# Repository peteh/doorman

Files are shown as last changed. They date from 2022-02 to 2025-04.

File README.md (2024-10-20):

# Doorman

Doorman is an ESP32 or ESP8266 based mqtt bridge to connect your [TCS](https://www.tcsag.de/) or [Koch](https://www.kochag.ch/) Intercom to any home automation system.

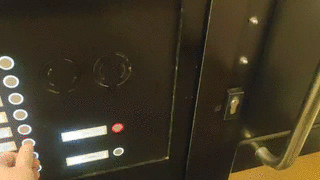
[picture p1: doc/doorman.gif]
doorman opener


## Main Features

* Support for TCS bus based intercom systems from TCS AG (Germany) or Koch AG (Switzerland)
* Automatic Homeassistant discovery via MQTT
* MQTT integration for all messages read from the bus and for writing messages to the bus
* Button push pattern detection - you can define a pattern and assign a code that is written to the bus if the pattern is detected (Example: automatically open the door if the doorbell is pressed x times in a certain way). A successfully detected pattern is also published via mqtt.
* Party mode (When this is enabled, the door opener automatically opens if the door bell is pressed)

### Party Mode

When Party mode is enabled, a code (default: entry door buzzer code) is automatically sent when a certain code has been received on the bus (default: entry door bell code).

This allows you to enable party mode during a party and your guests can just enter by pressing your door bell when they arrive or go for a smoke.

Party mode can be turned on or off by using the switch on in Homeassistant, or by quickly lifting up you handset 3x (if your handset code has been configured correctly).

## How to get Codes

Connect doorman to an mqtt broker by setting up WiFi credentials and mqtt broker.

If you already have Homeassistant configured with the mqtt integration on the same broker, go to Settings -> Devices -> Doorman. You should see a text entity called "TCS Bus". This entity allows to read all messages from the bus and write to the bus. Do the action for the signal you want to get the code of (apartment door bell, entry door bell or lifting up your handset). In the history of the TCS Bus entity you should see all codes that have been read from the bus. Then you can copy the values to the configuration settings in the home assistant device.

The codes that are specific to your flat are the long ones (without 0000 prefix).

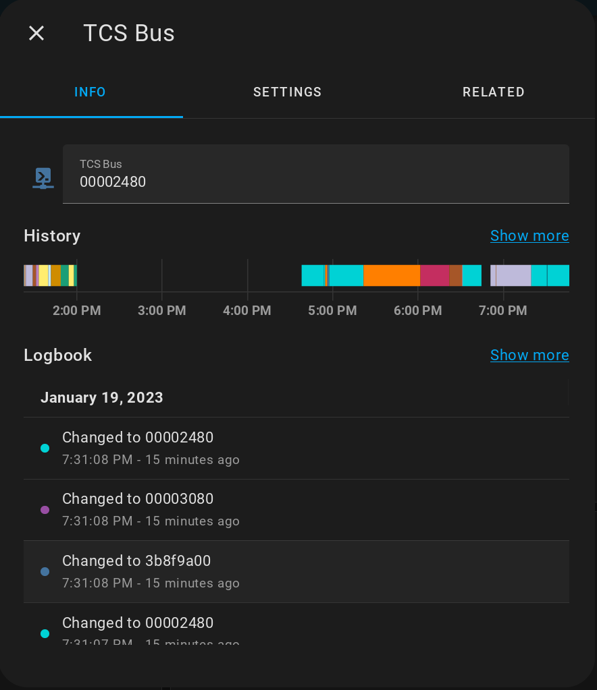
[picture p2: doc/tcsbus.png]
TCS Bus


## Prebuilt PCB and Case

AzonInc created a PCB with the doorman circuits and 3D printable housing. The project supports integration via ESPhome.

You can find more information [here](https://doorman.azon.ai) or in the [repository](<https://github.com/AzonInc/Doorman>).

## Wiring

wiring
If you open your phone in your flat (check TCS website for manuals), you will probably find the following screw terminal lines: A, B, E, P. 

A and B are the bus lines. You have to make sure which one is 24V+ and wire this to A of the setup. The other one is GND. 

The P line can be used for power supply. You can also skip the part and power through the USB port of the Wemos D1. 

### Part list

* 1x Microcontroller 1x (Choose one)
  * Wemos D1 Mini (based on ESP8266, does have single color led) [Buy on Amazon (partner link)](https://amzn.to/3VmqxsN) / [Buy on aliexpress (partner link)](https://s.click.aliexpress.com/e/_Dkct0Yl)
  * Wemos S2 Mini (based on ESP32-S2, does not have led) [Buy on Amazon (partner link)](https://amzn.to/3nkMbRq) / [Buy on aliexpress (partner link)](https://s.click.aliexpress.com/e/_Dnoy8df)
  * Wemos S3 Mini (based on ESP32-S3, does have RGB led)
* 1x ULN2003A (to send commands to the bus) [Buy on Amazon (partner link)](https://amzn.to/48Qoq6i)
* 1x Traco TSR1 2405 (dc/dc 24V to 5V as power supply for the controller to power it from the door bell system) [Buy on Amazon (partner link)](https://amzn.to/49iwwUZ)
* 1x tripple screw terminal (to connect to the bus) [Buy on Amazon (partner link)](https://amzn.to/3OrmcSC)
* 2x double screw terminal (optional, to connect switch and led) [Buy on Amazon (partner link)](https://amzn.to/3OrmcSC)
* 1x 1 MOhm resistor
* 1x 1 kOhm resistor
* 1x 147 kOhm
* 1x 10k Ohm resistor (only needed to wire a button)
* 1x 330 Ohm resistor (only needed to wire a led)
* 2x 1.2 Ohm resistors

## TODO

There are still a view things open.

* Allow wifi/mqtt configuration without the need for project compilation

## Credits

Doorman is heavily built on the code and the information of the following two projects:

**Doorman S3** PCB and case for TCS intercom with ESPhome firmware \
<https://github.com/AzonInc/Doorman>

**TCSIntercomArduino** different methods to read from and write to TCS bus \
Reverse Engineering video: <https://www.youtube.com/watch?v=xFLoauqj9yA&t=11s> \
<https://github.com/atc1441/TCSintercomArduino>

**tcs-monitor** an mqtt monitor for listening to the TCS bus \
Blog Post: <https://blog.syralist.de/posts/smarthome/klingel/> \
<https://github.com/Syralist/tcs-monitor>

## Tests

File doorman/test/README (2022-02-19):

This test set can be used with platformio's unity.h environment.

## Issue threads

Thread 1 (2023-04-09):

TCS-Reader Question

manuelkamp, 2023-04-09:
Hi, can you please explain to me how exactly the TCS Reader works? Unfortunately I am not very familiar with the used language in this project as is. As I am working on a similar project (but on raspberry pico with micropython), and my approach is not really working (I get a different message every time I ring my bell), I appreciate any help and/or explanation. What really confuses me is the fact, that one message I have recorded seems to be the correct one, If I am writing this message to the bus, my bell rings. But as I said, my reader reads a different message every time (and therefore it is not reliable). thank you very much!

peteh, 2023-04-10:
Hi,

you can start with the youtube video from the credits from me readme. I took the code from these projects for reading the data.

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

My guess is that your code is not accurate enough for the timing as it's pretty important to interpret the numbers right. That's why the interrupt based routine that I use in my code is most reliable from what I've tried so far.

peteh, 2023-04-12:
I'll close here and reopen if there are further questions

Closed 2023-04-12.

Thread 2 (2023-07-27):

Writing to bus not working.

BuergerJulian, 2023-07-27:
Hello,
i'm in the process of using the project.
Reading the bus is no problem, but writing doesn't work in my case.
When I send the code to open the door, nothing happens.

am i the only one with the problem?

Best Regards
Julian

peteh, 2023-07-27:
Not sure if many people use it. I'm using two of the devices. I've one 8266 d1 wemos and one s3 mini currently working with both reading and writing. Did you double check the wiring?

BuergerJulian, 2023-07-28:
Yes is rechecked the wiring, it looks okay.

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

peteh, 2023-07-28:
Can you take a high def picture of your wiring setup and a separate one where you connected to the bus? Otherwise it's kinda impossible to see what is wrong.

If you send codes manually it probably shows up there too but during writing reading is disabled. Thus it is not read from the bus but published based on what were were writing.

BuergerJulian, 2023-07-28:
Please don't laugh at soldering skills, I don't do that very often.

I hope you can see something.

Green = A (24V BUS)
White = B (GND)
Orange = P (24V)

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

peteh, 2023-07-28:
Normally the power line of the door bell should be sufficient. Only the bus 24v goes to 0 when sending a message. But if you can use a USB power supply it's also fine.

Glad you figured it out. You're officially the third person that I know of that uses this project after me and my neighbor :D

BuergerJulian, 2023-07-28:
It's a great project!
I would have thought more people would use it.

How can it be that there is no longer any voltage on the P line when I execute the command?

When I press the original door opener it doesn't happen.

It would be really nice if it would work without an extra power supply. So I have to lay an extra cable across the hallway.

peteh, 2023-07-28:
Good question,

normally it should not happen and means that the system detected a fault and is power cycling. It can happen if you send 0000 for example or commands the system cannot handle. So if you disconnect P line from the device and you still measure a drop to 0 on the P-line that does not happen when you press the door opener button, something is still wrong and it's not a power supply issue.

Only the A or B line from the bus should be pulled to 0 when sending commands. My powerline is stable for several weeks. You can see in the devices view in homeassistant under diagnostics of the doorman device the restart counter. If it power cycles it will increase that counter if you get your power from the P line.

Is your command actually executed - as in, does the doorbell ring if you send the ring code or does the buzzer open the door?

Can you double check the resistors on the board and their values?

There is a great video from Aaron where he explains how the system works: https://www.youtube.com/watch?v=xFLoauqj9yA

I built doorman based on the two projects linked in the credits of the readme as I'm not an electrician but rather a software guy. Maybe the video can give you some ideas what to check.

BuergerJulian, 2023-07-28:
I'm using a 150k resistor instead of the 147k, do you think that will make a big difference?

peteh, 2023-07-29:
The 147k Ohm resistor is for the voltage divider to scale down the 24V to 3.3V for the inputs. It does not impact the writing part of the device. You have to double check everything around the ULN2003 that is related to writing.

I also have no idea yet what else to check. Are you by accident sending 0000? Are you using the buttons to send the commands or the tcs bus text field in homeassistant, or directly via mqtt?

BuergerJulian, 2023-07-30:
> edit: I had another idea, do you maybe have a short from P line and 24V+ bus line? Does the issue happen that P goes to 0 if you don't connect it to the board? To test: only connect A and B to the door bell and leave P disconnected and power the board via USB. If P does not go down in this case your wiring of the P-line on the board is somewhere faulty.

Yes, that's the problem.
Now i just need a solution for this.

peteh, 2023-07-30:
You can try to find the short on the board by tracing the lines with a multimeter after you removed potential shorts.

By the way, I'd recommend to install the esp32 using female headers to add or remove the controller easier when you mess up the board:

https://gct.co/connector/bd080

As the other components are fairly cheap, you can have several iterations of the board. I'm using 1 strand wires with isolation rather than big solder blobs to make the connections. Still a pain in the ass to solder but a bit cleaner.
Mine for example looks like this:

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

BuergerJulian, 2023-07-30:
I soldered everything again, but I still have the same problem.
Brown = P 24V
White = B GND
Green = A 24V

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

peteh, 2023-07-30:
Looks ok from the front side. Can you also show the back side again?

Just for my understanding, does the controller turn off/restart when it's not powered by USB but only connected to P line when you send a message?

How are you measuring that the P line goes to 0? By measuring GND and P directly at the screw terminals of the intercom? How long does it stay at 0?

BuergerJulian, 2023-07-30:
> Looks ok from the front side. Can you also show the back side again?
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
>
> Just for my understanding, does the controller turn off/restart when it's not powered by USB but only connected to P line when you send a message?
Yes, exactly.
>
> How are you measuring that the P line goes to 0? By measuring GND and P directly at the screw terminals of the intercom? How long does it stay at 0?
Yes, I measure between GND and P on the terminal.
The voltage stays at 0v for about 1-2 seconds.

peteh, 2023-07-30:
Let's try to narrow it down a bit:
Sending wrong commands: we can exclude that because P line stays up when powered through USB

Wiring: I couldn't find obvious issues in your wiring yet, I can't double check the resistor values but I assume that you measured them before you soldered. So maybe nothing wrong there either.

Power consumption. If I remember correctly the data sheet says we have about 100 to 200mA at 24V for a connected device on the bus which should be plenty. The traco can provide up to 1A at 5V. I don't know what happens when you draw more. 1A should be plenty for the setup though. The only difference here is that you're using another dev board than me. I think yours has a few more parts on it than a d1 mini/s2 mini/s3 mini - those I've tested working in my setup and with stable power supply. I doubt you have one of those lying around to exclude the dev board though.

Other ideas I currently don't have yet

BuergerJulian, 2023-07-30:
I have now ordered a d1 mini,
I'll try it with that tomorrow.

Thanks for your help!

BuergerJulian, 2023-07-31:
Also not working with the d1 mini :(

peteh, 2023-07-31:
Then I'm also a bit at the end. Can you take a picture of the intercom itself and the wiring maybe?
Worst case you have to go with the usb power method for now.

BuergerJulian, 2023-08-02:
> A few more ideas from more likely to less likely being an issue after reading about similar issues in other projects:
>
> * Many people suggest to add capacitors when brownouts happen (high current peaks that we probably generate when we want to send messages followed by the power supply not being able to provide them quickly). It would charge and then the esp could use the charge from the capacitor rather than pulling from the psu. However, I've never needed them so far, so I have no idea how to wire them properly into the circuit. But maybe a good next approach to try.

> * What's the actual voltage on the bus and the P line? Is it actually 24V?

B -> P = 22V
B -> A = 24V

> * Are P line and one of the bus lines potentially shorted on the board or on the actual intercom?

I do not think so.

> * How long are the cables actually? I don't think voltage drops are a big issue, but if you use very long cables it might.

My cables are only 10cm long.

The microcontroller only draws 23mA, even if I send a command, I just measured that.

peteh, 2023-08-02:
Mhm, then I have no further ideas. I'd personally still try the capacitor solution, but other than that I'd probably go for a separate power supply then.

peteh, 2024-01-24:
@BuergerJulian If you are still interested in getting yours to work, check out  #4

He solved it using a cap to stabilize power supply.

BuergerJulian, 2024-01-25:
> @BuergerJulian If you are still interested in getting yours to work, check out #4
>
> He solved it using a cap to stabilize power supply.

I will give it a try, thank you!

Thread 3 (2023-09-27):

Installation/Compiling instructions/documentation

mStirner, 2023-09-27:
Hey,

first, thanks for the project/work.

I wanted to start using it, but have no clue how to compile/build the project and how to flash it.
Would it be possible to write a short guide/documentation on how to build and flash it?

Thanks in advance.

peteh, 2023-09-27:
Hi Marc,

I think adding detailed instructions is a bit redundant as it's the standard way to open a project in vscode with platform io and flash it to a standard dev board.

You will need vscode with platformio extension installed on your pc.

You will have to rename config.h.sample to config.h in the project and enter your wifi/mqtt details.

You can more or less follow this instruction about how to build a project with platform io: https://www.youtube.com/watch?v=nlE2203Q3XI

Let me know if you get stuck somewhere after watching the video.

mStirner, 2023-12-03:
Sorry for the late response.

I cant use PlatformIO, it throws a error when i try to open "PIO Home" in VSCode. (https://github.com/platformio/platformio-vscode-ide/issues/3912)
Is there a way to build & upload the project from a other way, especially the sample codes?

peteh, 2023-12-03:
You can always build in Arduino IDE.

1. Rename the main.cpp to main.ino
2. You might have to remove the Arduino.h import in main.ino
3. You have to manually install all the libraries that are listed in platformio.ini

Platformio is pretty stable if you don't run on 4 year old LTS versions of your operating system (based on your kernel I assume you are running ubuntu 20.04). My guess is that there is a python incompatibility because you are still on Python 3.6 while the most recent version is python 3.12 and most distros run on 3.10 or 3.11.

Your problem is this:
https://stackoverflow.com/questions/52796630/python3-6-attributeerror-module-asyncio-has-no-attribute-run

The functionality used that produces your error in platformio is because the functionality has only been added in Python 3.7 but you are running python 3.6.

If you want to use it on your old system, you could look into pyenv, but it's also a painful path.

My recommendation is to update to the latest LTS version which is 22.04. This would solve your issue as it ships with python 3.10.

dbro, 2025-05-12:
In case it's helpful for future reference, I can provide some comments here to guide people who want a walkthrough to install the platform IO command line version (does not involve VSCode).

clone the repository:
git clone https://github.com/peteh/doorman

install platform io by following the [installation instructions here] (https://docs.platformio.org/en/latest/core/installation/methods/installer-script.html) and also installing the [shell commands](https://docs.platformio.org/en/latest/core/installation/shell-commands.html) and the [udev rules](https://docs.platformio.org/en/latest/core/installation/udev-rules.html)

create a doorman/src/config.h file using the example from the repo, and edit the doorman/platformio.ini file if necessary (I needed to use /dev/ttyUSB0)

connect the device via USB, build and upload the firmware with this command: pio run -e d1-mini -t upload

visit the url assigned to the device by your DHCP server and continue setting up there

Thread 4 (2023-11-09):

No Codes :(

alkue1, 2023-11-09:
Hello,
I am enthusiastic about your project and have soldered together a board according to the instructions. Flashing the d1mini also worked without any problems. The connection to Homeassistant also works. Unfortunately, I do not get any values displayed in the TCS bus. Is it possible to narrow down the source of the error?
I have attached a picture of the circuit board and the wall unit.

I tried it with USB power supply, and also flashed different d1 minis. for the 147kohm I connected 100 and 47 in series.

Regards
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

peteh, 2023-11-19:
Mhm, hard to tell. Looks good from here at least.
Are you measuring something on the D5 pin? (measure with multimeter to GND). There we should measure something around 3V.
If you don't you could connect the P line instead of 24V+ from the bus to have a stable 24V and check again.

alkue1, 2023-11-20:
I have since found out that there was an occasional short circuit with very low currents on the board. I was able to solve the problem with a new board.  Now I can send and receive messages with power via USB

Now, unfortunately, I have the same problem as in the closed issue, that the power supply from the Traco breaks down during the transmission process.

I was also able to solve this problem with an external stepdown converter with two capacitors (like "DollaTek DC-DC 24V/12V to 5V"). Now I can send, but not receive

There is now approx. 3.05V on D5 and the voltage drops when a message arrives on the bus. Is 3.05 sufficient for reception?

I have also noticed a lot of noise in the loudspeaker when operating via P. Is there a way to avoid this?

Many thanks for the help and the great project

peteh, 2023-11-20:
> There is now approx. 3.05V on D5 and the voltage drops when a message arrives on the bus. Is 3.05 sufficient for reception?
>
That sounds alright, so the led on the wemos d1 is also not blinking, e.g. when you lift up the handset?
I just reflashed the latest master code to see if it's working in general and my led blinks when there is something on the bus, so the code should be fine.

If you want to run further tests, just write a small program that sends something over serial when the output of digitalRead(D5) changes. Then you can see if the D5 input works in general when you lift up the handle or press the door opener button on the tcs device.

> I have also noticed a lot of noise in the loudspeaker when operating via P. Is there a way to avoid this?
>
For me, I haven't noticed, but I'm also running on the traco. I'm unfortunately no electric expert, my guess is that the power supply of your TCS system is not handling this well (there are only some 100mW to be drawn from the P line per device).
> Many thanks for the help and the great project

alkue1, 2023-11-22:
> blinking, e.g. when you lift up the handset?

The software seems to work perfectly. The lamp now flashes briefly when sending and receiving.

> my guess is that the power supply of your TCS system is not handling this well (there are only some 100mW to be drawn from the P line per device).

i think you are absolutely right. It seems as if the power supply breaks down for som milliseconds and forces the d1 mini to restart. I have now added a relatively large capacitor in front of the traco. At the moment everything seems to be working as it should.  :)

The last step will be a PCB so that everything fits into the existing cover in the end.

Many thanks for the support - solved!

peteh, 2023-11-22:
If you're making a pcb I'm very interested in having one or two as well and I'd also add the pcb files to the repo if you share them.

I'm also interested in your capacitor solution which could maybe solve the problem of the person from the other issue. Then I could include it in general in the drawings.

Closed 2023-11-22.

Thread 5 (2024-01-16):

"esp_task_wdt.h" missing when building project

NonProgrammerCharacter, 2024-01-16:
**Description:**
When building the project for a d1-mini in VsCode with Platformio on Windows I get the following error message.
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

I have tried finding where that file comes from but I can only find it online as part of this github "https://github.com/pycom/esp-idf-2.0/blob/master/components/esp32/include/esp_task_wdt.h".
Is it part of some ESP32 libraries which cant be used on a ESP8266 board?

**Trace:**
```
Processing d1_mini (platform: espressif8266; board: d1_mini; framework: arduino)
--------------------------------------------------------------------------------------------------------------------------------------------------------------------------------------------------------------------------------------------Verbose mode can be enabled via `-v, --verbose` option
CONFIGURATION: https://docs.platformio.org/page/boards/espressif8266/d1_mini.html
PLATFORM: Espressif 8266 (4.2.1) > WeMos D1 R2 and mini
HARDWARE: ESP8266 80MHz, 80KB RAM, 4MB Flash
PACKAGES:
 - framework-arduinoespressif8266 @ 3.30102.0 (3.1.2)
 - tool-esptool @ 1.413.0 (4.13)
 - tool-esptoolpy @ 1.30000.201119 (3.0.0)
 - toolchain-xtensa @ 2.100300.220621 (10.3.0)
LDF: Library Dependency Finder -> https://bit.ly/configure-pio-ldf
LDF Modes: Finder ~ chain, Compatibility ~ soft
Found 44 compatible libraries
Scanning dependencies...
Dependency Graph
|-- ArduinoJson @ 6.21.5
|-- PubSubClient @ 2.8.0
|-- libesplog @ 0.0.1+sha.335d30f
|-- libmqttdisco @ 0.0.1+sha.af15d5c
|-- ArduinoOTA @ 1.0
|-- DNSServer @ 1.1.1
|-- ESP8266mDNS @ 1.2
|-- ESP8266WebServer @ 1.0
|-- ESP8266WiFi @ 1.0
|-- LittleFS @ 0.1.0
|-- tcsbus
|-- pattern
Building in release mode
Compiling .pio\build\d1_mini\src\main.cpp.o
Archiving .pio\build\d1_mini\lib328\libPubSubClient.a
Archiving .pio\build\d1_mini\lib316\libesplog.a
Archiving .pio\build\d1_mini\lib1d7\libmqttdisco.a
Compiling .pio\build\d1_mini\liba26\ESP8266WiFi\WiFiClientSecureBearSSL.cpp.o
Compiling .pio\build\d1_mini\liba26\ESP8266WiFi\WiFiServer.cpp.o
Compiling .pio\build\d1_mini\liba26\ESP8266WiFi\WiFiServerSecureBearSSL.cpp.o
Compiling .pio\build\d1_mini\liba26\ESP8266WiFi\WiFiUdp.cpp.o
Compiling .pio\build\d1_mini\liba26\ESP8266WiFi\enable_wifi_at_boot_time.cpp.o
Compiling .pio\build\d1_mini\lib938\ESP8266mDNS\ESP8266mDNS.cpp.o
Compiling .pio\build\d1_mini\lib938\ESP8266mDNS\LEAmDNS.cpp.o
Compiling .pio\build\d1_mini\lib938\ESP8266mDNS\LEAmDNS_Control.cpp.o
Compiling .pio\build\d1_mini\lib938\ESP8266mDNS\LEAmDNS_Helpers.cpp.o
Compiling .pio\build\d1_mini\lib938\ESP8266mDNS\LEAmDNS_Structs.cpp.o
Compiling .pio\build\d1_mini\lib938\ESP8266mDNS\LEAmDNS_Transfer.cpp.o
Compiling .pio\build\d1_mini\lib85e\ArduinoOTA\ArduinoOTA.cpp.o
Compiling .pio\build\d1_mini\lib720\DNSServer\DNSServer.cpp.o
Compiling .pio\build\d1_mini\lib3ba\ESP8266WebServer\detail\mimetable.cpp.o
Compiling .pio\build\d1_mini\lib68b\LittleFS\LittleFS.cpp.o
Archiving .pio\build\d1_mini\lib3ba\libESP8266WebServer.a
src\main.cpp:27:10: fatal error: esp_task_wdt.h: No such file or directory

**********************************************************************
* Looking for esp_task_wdt.h dependency? Check our library registry!
*
* CLI  > platformio lib search "header:esp_task_wdt.h"
* Web  > https://registry.platformio.org/search?q=header:esp_task_wdt.h
*
**********************************************************************

   27 | #include <esp_task_wdt.h>
      |          ^~~~~~~~~~~~~~~~
compilation terminated.
*** [.pio\build\d1_mini\src\main.cpp.o] Error 1
======================================================================================================== [FAILED] Took 3.43 seconds ========================================================================================================
```

NonProgrammerCharacter, 2024-01-16:
Now it went through flawlessly.

I assumed it wasn´t meant to be used on the ESP8266, at least the watch-dog stuff but wasn´t sure.

Thank you for the patch.

Closed 2024-01-16.

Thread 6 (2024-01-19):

Integration for the E terminal line

NonProgrammerCharacter, 2024-01-19:
**Help Wanted** (as I can not add labels)

Is it possible to integrate the E line into the microcontroller, which is used for the bell button in front of the apartment door, so I can work with it in Homeassistant?

I would only want it to be the same like the the bell button on the front door, but I guess this one does not run over the bus, so it would only need to register if there is a signal or not which I then would use to create a signal in Homeassistant I can automate with.

This is my first little project and pretty much my first time wiring, soldering and programming stuff like this so it´s a little to much for me.
Im only asking for help with the wiring, the programming I would probably manage by myself somehow.

NonProgrammerCharacter, 2024-01-20:
I dont understand what you mean with wire a relay, wouldnt I just have to look what voltage runs through the contact when the button is pressen and use an appropriate resistor to reduce it to a ESP usable level and wire it to an input (as far as I understood this)?
I only want to see on the ESP if the button is pressed as I would then programm Homeassistant to send a signal to my phone and maybe open the apartment door (with a Nuki Smart Lock or something).

I mean the third bell wire, A, B, E and P, E is used for the bell button directly infront of the apartment door.

This one is not the correct modell but the same contacts, my configuration is with only 3 wires (rightmost graphic) with only A, B, E. (it´s in german, should be a problem as the text is irrelevant for this)
https://www.tcsag.de/fileadmin/user_upload/TCS_DE/Metanavigation/Downloads/ARCHIV/Innenstationen/PI_TTS2.pdf

peteh, 2024-01-20:
Ah now I think I get it. I thought we are talking to simulate a press on the "Etagenruftaster".

Measure what's the voltage. I guess it's around 24V when it's pressed as it connects to the P line when pressed.

Thus you should be able to use the same voltage divider as used for bus reading.

When you look at the wiring:
https://github.com/peteh/doorman
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
Check the green cable going from Bus 24V through the resistors and into the blue cable.

That's a voltage divider that reduces the 24V down to the ESP-readable range.

Wire the same setup with identical two resistors to another input (maybe measure before to get a 0V and ~ 3.3V signal when pressing the switch).

Then you can either read the state with digitalRead in every main loop cycle or add another interrupt routine for the new input.

You probably have to debounce it as well.

peteh, 2024-01-20:
@NonProgrammerCharacter

I created a branch and PR with the necessary changes: feature/etr

See the PR for details: #7

I cannot test it though. However, if you put a voltage divider on D7 it should work.

PS: are you sure the system puts no code on the bus when the floor button is pressed? If it does I can also create an entity that just reacts on a code which would be less wiring.

NonProgrammerCharacter, 2024-01-22:
Based on your drawing the new voltage divider should connect to 5V on the D1-mini, I guess thats not supposed to be like that so I connected it to GND (I couldnt find a better looking software which had the parts needed, which programm did you use for your graphic?).
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

I think you took the wrong input ID, should be D0 not D7 as that is already in use. (its wrong in the code also)

I checked now and there is no signal on the bus when pressing the door bell infront of the door.

At the same time I have noticed the listening to the bus is realy unreliable as I often (60% of the time) have no code in the log.
I can see the LED on the board react when picking up the phone or pressing the bell but no entry in the logbook.
I have reinstalled the mqtt-broker (as the device disappeared sometimes and I hoped to fix booth problems) and even installed a different one but no improvement for now.

Havent checked the voltage on "E" yet.

peteh, 2024-01-22:
> Based on your drawing the new voltage divider should connect to 5V on the D1-mini, I guess thats not supposed to be like that so I connected it to GND (I couldnt find a better looking software which had the parts needed, which programm did you use for your graphic?).

You are right, my drawing was a bit unprecise. Voltage divider should go to GND, not to 5V.
I used fritzing. It's not great, not terrible. The project is in the doc folder (wiring.ffz).

>
> I think you took the wrong input ID, should be D0 not D7 as that is already in use. (its wrong in the code also)
>
I deliberately used D7 because D0 is used for boot and wakeup in the d1 mini which might cause issues when starting the controller.
D7 is used in the wiring drawing but actually no code is using it yet. So I thought that I might remove the connectors on it in a future iteration as I haven't found a use case.

If you don't want to use D7, I'd recommend D1 or D2. Let me know which, then I can also update the code.

> I checked now and there is no signal on the bus when pressing the door bell infront of the door.

By "the door bell infront" it's the ETR Etagentaster?

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

Before you wire, check if you see a voltage change of 24V when pressing the button. Then we know that we could at least expect it to work.

NonProgrammerCharacter, 2024-01-23:
> You are right, my drawing was a bit unprecise. Voltage divider should go to GND, not to 5V.
> I used fritzing. It's not great, not terrible. The project is in the doc folder (wiring.ffz).

Ah fritzing, I stumbled upon that but could not test it as it was pay-to-download.
I used TinyCAD, not that happy with it as it too has limited parts and it does not look good enough to warrant the limited parts, the esp8266 is imported from here. "https://forum.arduino.cc/t/how-to-make-a-schematic-you-can-post/675103/10"

> I deliberately used D7 because D0 is used for boot and wakeup in the d1 mini which might cause issues when starting the controller. D7 is used in the wiring drawing but actually no code is using it yet. So I thought that I might remove the connectors on it in a future iteration as I haven't found a use case.
>
> If you don't want to use D7, I'd recommend D1 or D2. Let me know which, then I can also update the code.

Ahh, thats fine then, I too didn´t use it so D7 is ok

> By "the door bell infront" it's the ETR Etagentaster?

Yes. Apartment bell button is probaly the better term.

> Before you wire, check if you see a voltage change of 24V when pressing the button. Then we know that we could at least expect it to work.

I will try, kinda hard with my tools as I dont have 4 hands and my voltage tester doesnt have clamps. But I guess it does. I only have three lines in my bell, A, B and E, so it should go to A.
Will test when possible.

NonProgrammerCharacter, 2024-01-23:
Ah well good to know with fritzing, but it kinda grew on me to have more technical and less good looking graphic.

I use the ETR, and it propably had to do with the wifi problems but now I have a code for it, so no extra wiring needed.
Most likely I just didnt see the LED flashing and together with the code and my missing P line I went straight to "just a button".

Well thanks for the help on this issue and sorry for all the work only for it to be a false alarm.

peteh, 2024-01-23:
No worries, I think I managed to improve the wifi code a bit and will continue to do so. At least it should not reset randomly by blocking through wifi disconnect.

Closed 2024-01-23.

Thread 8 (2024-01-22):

Bus is only read sometimes because WiFi is not properly connected

NonProgrammerCharacter, 2024-01-22:
Listening to the bus is realy unreliable as I often (60% of the time) have no code in the log.

I can see the LED on the board react when picking up the phone or pressing the bell but no entry in the logbook.

I have reinstalled the mqtt-broker (as the device disappeared sometimes and I hoped to fix booth problems) and even installed a different one but no improvement for now for this problem (the esp stopped disappearing).

This is the wiring at the moment with external powersupply and without the parts for button and led.
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

peteh, 2024-01-22:
Very likely. I was going to suggest to check wifi signal.

If the led blinks it means it successfully reads the code. If you can't see a code in your broker it means it could either not connect to wifi or not connect to the broker. Wifi is probably the more realistic cause. In either case it will also block the main loop and if it takes to long the esp8266 might just reboot which means the read code will also be lost.

I have it on my todo list to handle wifi disconnects in a non-blocking way but haven't had time yet.

You can use Wifi Analyzer on Android to check if there might be a better channel for your 2.4 Ghz network to improve the performance without moving the router.

peteh, 2024-01-22:
> I already moved it, was supposed to be moved anyway, even if only a little but it worked for now, ping atleast has a 98% connectivity quote now, question would be what happens if the esp tries to send a code but cant reach the broker, will it even retry or lose that signal?

It depends a bit, currently it tries to reconnect. However I recently found out that you are not supposed to block the main loop for more than 6s. So it would probably just restart if it can't connect within 4s.

We could actually see if it restarts. Go into devices in Homeassistant, go to Doorman and under diagnostics check if the Restart counter increases over time even if you don't restart it on purpose.

If it looks like this it probably looses connection to WiFi frequently and restarts:
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

>
> Already checked channel, sadly its realy full here, like every channel with 5-6 wifis and the fritzbox has strangely bad wifi (for its price, should have tried another router I guess). If it persists I guess I have to upgrade my wifi earlier than planned.

An upgrade probably won't help much as you are still limited to 2.4Ghz.

You could check if you can configure something for Fritzbox:

- Disable channel hopping if enabled and set a fixed channel
- Set bandwidth to 20Mhz instead of 40Mhz if possible (lower throughput but less cross talk)\
- Force 5Ghz wifi on your other devices where possible

NonProgrammerCharacter, 2024-01-23:
I have uploaded it now to the esp and it atleast didn´t break it.
I dont know if I will see an improvement as it did not restart since moving the router and it was kinda complicated to move so I realy dont want to move it back only for testing this.

With upgrading I meant getting a mesh repeater or trying D-LAN-AP, have to do it anyway propably as I have some bandwith problems in some rooms which didn´t bother me enough to upgrade it.

I will inform you if I see the restart counter increasing (without me killing the power).

But this patch seems to have fixxed another problem I stumbled upon which im not sure realy was one.
When picking up the phone multiple times in a row the led on the esp seemed to stop reacting and stayed on, after multiple seconds it would shut off and start working again. I could not reproduce the "stop reacting" but I can reproduce the LED staying on and now it still blinks when reading the bus.
Not a huge problem but maybe at the end of the loop shut the led off.

peteh, 2024-01-23:
@NonProgrammerCharacter That's not a bug, it's a feature. When you lift the handset 3 times with less than 2 seconds time inbetween, it will switch Party mode on (sends buzzer signal when somebody rings at the downstairs door). To show that party mode is on the led signal is inverted. On esp32 with rgb led I switch to a different color

It's the same as setting party mode to on in homeassistant.

Maybe it would be more reasonable to use a button for this :D

NonProgrammerCharacter, 2024-01-23:
Ahh, I missed that in the README.

Well then I dont know why it didn´t work before, maybe it didn´t like not having any codes configured but getting switched to party mode.

Button I wouldn´t say is needed, this system works fine, maybe give the option to switch it to a different code (a more intuitive way than changing the "Handset Liftup Code" to a different one, I have a button to switch on the lights on the staircase, I think it would be a better choice to use that button (if possible) instead of the handset.

LED, well I guess we still need that one output if someone want an LED for partymode, I most likely wont use it.

I had some questions regarding the pattern-codes, should I open a new issue for that? There isnt realy much written in the README and the description on the config page (directly on the esp) makes it even more complicated.

peteh, 2024-01-23:
Open a new issue please. I haven't written much about it because currently it's just hardcoded and I was not motivated enough to find an intuitive way to configure or record a pattern.

For the led: I currently just use the led on the controller itself. Party mode on = led is on. On esp32 with rgb led it has different colors.

peteh, 2024-01-27:
I'll close this issue as reading is currently fine after stabilizing wifi.

Closed 2024-01-27.

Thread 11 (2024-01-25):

General questions to functionality and possible problems

NonProgrammerCharacter, 2024-01-25:
I had some questions regarding functions, I can split the issue if needed and I would try to add it to the Readme if that would be okay (I like documentation)

**1:**
How exactly do I create a pattern to be recognized? If I understand description on the "codes" page running on the ESP they should be a hexadezimal number, how do I write a pattern in hexadezimal, or is it meant as "if this code is detected..."?
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

**2:**
If I understood the project-code correctly, if I press one of the "Controls" on the device in Homeassistant the ESP sends the configured code on the bus and the correlating function should happen (door opener, bell rings) right? If not the text after this can be ignored as its written with the assumption that it works that way.

Its not working for me as it does not happen with any "Control" I try to activate, no bell and no opener.
I can see that the code change on the bus but nothing else happens.

I have checked the codes multiple times and they should be correct so I dont know why it does not work.

peteh, 2024-01-25:
> **1:** How exactly do I create a pattern to be recognized? If I understand description on the "codes" page running on the ESP they should be a hexadezimal number, how do I write a pattern in hexadezimal, or is it meant as "if this code is detected..."?

You have to differentiate code and pattern. To be fair I didn't put much thought into it to make it intuitive especially with the wording.

Apartment Door pattern code and entry door pattern code can be technically any code you want.
If the code is detected on the bus in the defined pattern, it will trigger the sensor.

Example:
Entry Door pattern code: 0x1234 (entry door bell code)
Entry Door pattern (currently hard coded in the program): code, 1000ms quiet, code, 1000ms quiet, code.

So if you press the entry door bell 3 times with pause of 1 second it will trigger the Entry Door pattern detected sensor AND also trigger the Door opener.

For the apartment door pattern it will only trigger the apartment door pattern detected sensor because there is no door opener for that.

The pattern itself is currently hard coded and defines the pause in milliseconds that should be detected between two codes of the pattern:
```cpp
    // configure pattern detection
    patternRecognitionEntry.addStep(1000);
    patternRecognitionEntry.addStep(1000);

    // configure pattern detection
    patternRecognitionApartment.addStep(1000);
    patternRecognitionApartment.addStep(1000);
```

Currently this results in the pattern being detected if you press 3 times with a pause of 1s between each. The pause can be inaccurate to a certain extend, e.g. 800ms or 1200ms will still be considered correct.

> **2:** If I understood the project-code correctly, if I press one of the "Controls" on the device in Homeassistant the ESP sends the configured code on the bus and the correlating function should happen (door opener, bell rings) right? If not the text after this can be ignored as its written with the assumption that it works that way.

The assumption is correct.
>
> Its not working for me as it does not happen with any "Control" I try to activate, no bell and no opener. I can see that the code change on the bus but nothing else happens.
>

Unfortunately it can be a bit misleading that you see the code in the bus entity. When you send a code, reading will be disabled during that time while the code is written physically to the bus. So there is actually no real code read from the bus while you send using doorman. However, the code is injected into the entity to be logically consistent. It will be shown but it wasn't physically read. As a result, if writing doesn't work, e.g. because the wire is wrongly connected, it will still show up in TCS bus. This was done because reading and writing at the same time can lead to timing issues in the controller.

> I have checked the codes multiple times and they should be correct so I dont know why it does not work.

The reason is that writing to the bus does not work for whatever reason.

As actual reading codes from the bus while you press the door bell or lift the handle or anything else works as I understand from your previous posts it means that only the writing part is wrong for some reason.

To correctly set it up you should try the following.

1. Press your actual apartment door bell outside of your apartment
2. Note the code you see on the bus, e.g. 1b8f9a41
3. Copy and paste the code into "Apartment Door Bell Code" either on the home assistant device page or on the web interface and press save
4. Press the Apartment Bell Switch of the device in homeassistant
5. Now your door bell should ring if everything works

If it's not the case you have to double check the wiring on the following path which is for writing to the bus:
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

- Did you wire the correct output pin of the ESP?
- Did you solder the correct resistor values?
- Are there any shorts or broken connections on the path?
- Is the ULN2003A soldered in the correct orientation, it has a mark at the top?
- Is it really an ULN2003A?

NonProgrammerCharacter, 2024-01-28:
> You have to differentiate code and pattern. To be fair I didn't put much thought into it to make it intuitive especially with the wording.
>
> Apartment Door pattern code and entry door pattern code can be technically any code you want. If the code is detected on the bus in the defined pattern, it will trigger the sensor.

Ahh ok, thats what I thought.
Yea kinda confusing, we talk about pattern for pressing the button and "Entry Door Bell Pattern" sounds alot like that, code would be a better term for it and I guess the correct one.

> Unfortunately it can be a bit misleading that you see the code in the bus entity. When you send a code, reading will be disabled during that time while the code is written physically to the bus. So there is actually no real code read from the bus while you send using doorman. However, the code is injected into the entity to be logically consistent. It will be shown but it wasn't physically read. As a result, if writing doesn't work, e.g. because the wire is wrongly connected, it will still show up in TCS bus. This was done because reading and writing at the same time can lead to timing issues in the controller.

Ahh, ok I guess thats my problem then.

> * Did you wire the correct output pin of the ESP?
Checked.
> * Did you solder the correct resistor values (you can click on the resistors in fritzing and double check the values)?
Didnt solder yet, wanted to check if it works before soldering so used a breadboard.
I used a collor picker for resistors to get the value, double checked and everything just now.
> * Are there any shorts or broken connections on the path?
Havent found any just now, rebuild everything just to be sure
> * Is the ULN2003A soldered in the correct orientation, it has a mark at the top?
Checked.
> * Double check if the GND connection of the ULN2003A is correctly wired in connects to GND
Checked.
> * Is it really an ULN2003A?
Well I bought one, on it is written "ULN2003L", I know far to less about those to know if that is compatible or not.

Rewiring it sadly didnt help, still nothing when using the controls in Homeassistant, is the problem the "ULN2003L"?

peteh, 2024-01-28:
> Well I bought one, on it is written "ULN2003L", I know far to less about those to know if that is compatible or not.
>Rewiring it sadly didnt help, still nothing when using the controls in Homeassistant, is the problem the "ULN2003L"?

It should not if as the difference of A (long legs for through hole soldering) and L (short legs for on board flat soldering) seems to only be packaging and the chips should be identical.
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
NonProgrammerCharacter, 2024-01-29:
I tried another ULN, if its broken or something as I got multiple (if im paying 18€ for delivery better get multiple) sadly didnt help.

Here is a pic, I removed the parts not used / needed atm for better overview.
I marked the green line start and ends for the same reason.
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

peteh, 2024-01-29:
The wiring looks reasonable.

Did you measure the resistors with a multimeter or just by color coding?
If just by color coding I would still measure each of them with a multimeter just to be sure.

Can you also make a screenshot of your code settings?
For my door opener it's 00001100.

NonProgrammerCharacter, 2024-01-29:
I did not measure all resistors, I only had to color code your graphic as it wasnt written which resisitor goes where.
They came labeld with their value so I dont think thats a problem. (I just checked all used for writing to the bus)

But I saw that the 1.2 Ohm resistors only show 0.2 on my (realy cheap) multimeter but they all do (got 20 or so) so not sure if thats a problem or just my multimeter beeing unprecise on low values.

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

Its the same code for me.

NonProgrammerCharacter, 2024-01-30:
> Just to make sure, you have to measure them outside of the circuit.

Oh? I didnt know that, they have 0.6 Ohm outside of the circuit.

peteh, 2024-01-30:
Which is still weird. If you measure them as one single resistor you should have 1.2Ohm. If you measure them while they are parallel you should measure 0.6Ohm.

If you measure just 0.6Ohm for one resistor you can just put a single resistor instead of two.

NonProgrammerCharacter, 2024-01-31:
I realy think its my multimeter, I have two different 1.2 Ohm resistors from different shops and booth have 0.6 Ohm and some 1.5 Ohm resistors which measure 1.1 Ohm.

But I can try it anyway, I dont know what else to try besides rewiring again, maybe on a different board if there is a short.

Other than that im kinda clueless what alse to try besides soldering it and hoping it works.

peteh, 2024-01-31:
I also don't know how to further debug.

You could still try a different power supply for the d1 mini. Some people had issues with power supply and I probably should add a capacitor to the circuit in general.

The bus writing part is based on this project:
https://github.com/atc1441/TCSintercomArduino

You could try the single sketches from that repo and check if they work and maybe the creator has some more ideas what could be wrong.

You can run the sketches from platformio if you add
```
#include <Arduino
```
to the top of the ino files and rename them to main.cpp in a new platformio project.

NonProgrammerCharacter, 2024-02-06:
Well I was kinda demotivated after spending so much time on it and not even knowing why it didnt work so I picked it back up today when a colleague came over and was interested in it (not the problem) and after setting it all up again und plugin Homeassistant back in it just worked.
I didnt change anything from my last attempt so im stumped what the problem was, I guess maybe a falty connection on the board or something.

I tested all the controls and everything worked without a problem.

> You could still try a different power supply for the d1 mini. Some people had issues with power supply and I probably should add a capacitor to the circuit in general.

Dont think that should be possible in my case, im using a powerbank for it with up to 30 watts charging power.

Soo, gonna solder it soon and see if it still works.

peteh, 2024-02-07:
Awesome!

Thank you for the feedback. I'm not sure how long the power bank will last though. I haven't put any effort into reducing power consumption.

NonProgrammerCharacter, 2024-02-07:
Its only for testing purposes, I have a 24V transformator in my fuse box I will use I just wanted to get it working so I removed all unneeded components from the board.

The friend already expressed interest in building his own.

peteh, 2024-04-03:
@NonProgrammerCharacter I think this topic can be closed now. If there are other issues, then just open a new one.

Closed 2024-04-03.

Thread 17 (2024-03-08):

Board Design Frage

AzonInc, 2024-03-08:
Hi,

erstmal vielen Dank für dieses Projekt 💯

Ich bin derzeit dabei mit Hilfe deines Codes eine ESPHome Komponente zu schreiben (Ich werde das Ergebnis dann gern zur Verfügung stellen wenn alles funktioniert) und habe dabei auch im allgemeinen versucht die Hardware weitestgehend zu verkleinern und auf das Minimum zu reduziere,  damit das ganze problemlos in eine Unterputzdose hinter der Gegensprechanlage passt.

Nun hoffe ich dass ich dabei alle Verbindungen und Komponenten berücksichtigt habe und noch alles korrekt verbunden ist.
Der D1 Mini ist jetzt zum aufstecken vorgesehen, falls es mal zu einem Defekt kommen sollte.

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

Habe ich irgendwas beim Schaltplan vergessen?

peteh, 2024-03-08:
Sieht an sich OK aus. Die Widerstände habe ich nicht überprüft.

Du kannst theoretisch noch kleiner werden wenn du etwas wie einen  Seeed Studio XIAO ESP32S3 oder so nimmst. Der hat noch Mal einen kleineren Footprint ist aber teuer.

peteh, 2024-03-09:
Bin leider auch kein Experte für sowas aber direkt zwischen gnd und 5v vom traco DC/DC. Schau Mal durch die geschlossenen Tickets. Vielleicht findest du den Kommentar noch Mal.

AzonInc, 2024-03-10:
Ich hab mich heute mal an einen PCB Entwurf gesetzt:
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

peteh, 2024-03-10:
Du könntest überlegen auch einen neopixel drauf zu setzen so wie ich es beim s3 Mini nutze. Dann könnte man die gleichen Status verwenden und mit Farben mehr dar stellen.

Wenn du das Design produziert und getestet hast, kannst du es auch gern per pr hier mit rein mergen oder du gibst mir den Link zu deinen ESP Home Sachen, dann verlinke ich es.

Falls du mehrere produzieren lässt, würde ich dir auch einen abnehmen.

AzonInc, 2024-03-10:
Ich hab bisher verschiedene Layouts probiert aber ich glaube dass im aktuellen Formfaktor die ansteuerbare LED inklusive anderer dafür notwendiger Komponenten leider nicht rein passet. Stattdessen habe ich jetzt noch eine weitere LED und zwei GPIO Pin Header sowie einen MicroUSB Anschluss dazugepackt.

Das wäre der aktuelle Stand:
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

peteh, 2024-03-11:
Cool. 2 Fragen hätte ich noch.

Spricht irgendetwas gegen einen usbc Anschluss als Standard?

Und hast du einen Kondensator mit unterbekommen für die 5v vom traco mit unterbekommen?

AzonInc, 2024-03-11:
Ich habe nochmal Platz für den USB-C Connector gemacht, da dieser vorher aufgrund des größeren Footprints nicht hin passte.
Der Traco ist in dieser Variante einer der auf 3,3V regelt. Vor dem Traco ist die von Traco empfohlene Filterschaltung für dieses Bauteil - eventuell genügt das ja bereits:
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

Hier der aktuelle Stand:
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

AzonInc, 2024-03-11:
Hast du sonst noch Vorschläge was man da umsetzen kann?

peteh, 2024-03-12:
Vielleicht noch ein Zusatzbutton, den man dann frei integrieren könnte. Ansonsten weiß ich nicht ob es auch einen dropin mit esp32 s3 gibt. Der hätte meines Wissens etwas besseres WLAN.

AzonInc, 2024-03-13:
Hier nochmal der aktuelle Schaltplan. Ich gehe erstmal davon aus dass ich Fehler gemacht habe da ich auf dem Gebiet jetzt auch nicht wirklich viel unterwegs bin. Vielleicht erkennst du ja da ggfs. noch Probleme sofern welche existieren.

[TCS Intercom Bridge.pdf](https://github.com/peteh/doorman/files/14592241/TCS.Intercom.Bridge.pdf)

AzonInc, 2024-03-16:
@peteh was für einen ESP verwendest du derzeit bei dir direkt an dem Netz der Gegensprechanlage ohne externe Stromversorgung? Ich hab gesehen dass das Netzteil davon maximal 60mA rausgibt.

alkue1, 2024-03-16:
Hi,
ich habe mich mit diesem Projekt letztes Jahr schon ein wenig beschäftigt, konnte es aber aus Zeitgründen nicht zufrieden stellend beenden. Ich habe das Problem mit der Stromversorgung meines 8266 bei ebenfalls kleinem Netzteil mit einem 1500µF Kondensator (vermutlich viel zu groß) lösen können. Bei einem Signal brach bei mir die Stromversorgung des ESp zusammen, sodass keine Verarbeitung möglich war. Der Kondensator hat das Problem zunächst gelöst und das Projekt hat funktioniert.
Leider waren bei diesem Betrieb erhebliche Störgeräusche bei der Gegensprechanlage aufgetreten, die im Netzbetrieb nicht vorhanden waren. Hatte zunächst den Traco im Verdacht. Eine Filterschaltung wie oben habe ich aber nie ausprobiert.

Als alternative  bin ich vor kurzem über das Projekt ESPBell-MAX hier bei github gestolpert. Da ist eine fertiges PCB mit lion Batterie schon entwickelt. Wäre das auch eine Option? Man könnte ggf beide Projekte vereinen und mit überschaubarem Aufwand/Fachwissen/Anpassungen einen Batterie-betriebenen doorman erstellen?

AzonInc, 2024-03-16:
Ich musste heute leider auch herausfinden dass hier das Gerät in der Wohnung im Zwei-Draht-Betrieb läuft. Daher besteht keine Chance das direkt mit vom selben Netzteil abzuzapfen. Der Etagenruftaster ist hier an P und E angeschlossen (Auch wenn in der Installationsanleitung eigentlich was anderes steht).

Allerdings kann man in der aktuellen variante einfach eine andere Stromquelle per USB-C oder Connector (5-24V) anschließen.

peteh, 2024-03-17:
> @peteh was für einen ESP verwendest du derzeit bei dir direkt an dem Netz der Gegensprechanlage ohne externe Stromversorgung? Ich hab gesehen dass das Netzteil hier im Haus nur 60mA auf der P-Leitung rausgibt (maximal 100 für eine Minute). Der ESP32 wird aber wesentlich mehr ziehen - daher wäre eine Versorgung über das Netzteil der Gegensprechanlage bei mir nicht länger möglich. Du hast wahrscheinlich ein leistungsfähigeres Netzteil im Haus.

Ich vermute, dass hier im Haus ein dickeres Netzteil ist, da es mehrere Etagen hat.
Mein Nachbar unter mir sitzt am gleichen Bus und wir haben einen Wemos D1 mini (esp8266) und einen S3 Mini (ESP32 S3 https://www.wemos.cc/en/latest/s3/s3_mini.html) am gleichen Bus, beide mit je einem Traco stromversorgt.

Ich habe in beiden einen Resetcounter eingebaut und die Teile laufen seit Monaten stabil - also ohne Neustarts oder Brownouts.

AzonInc, 2024-03-18:
Okay dann sollte das weiterhin für dich passen, da ich auch den S3 verwende.
Ich hab mir mal den Schaltplan vom S3 Mini angeschaut und da scheint die WS2812B LED nur über 3,3V zu laufen. Demnach kann ich dir statt der zweiten normalen Status LED wieder die WS2812B integrieren.

Ich werde nächste Woche mal testen ob das mit dem Transistor Array Ersatz auch so passt und dann steht einem Produktionsauftrag eigentlich nichts im Weg.

AzonInc, 2024-03-25:
Ich stehe jetzt beim Testen vor einem kleinen Problem:

Wenn ich nun die Kabel an die GPIO anschließe bricht die Spannung zusammen.
Ich verwende bei mir GPIO22(read, orange) und GPIO23(write, gelb) .

Die a-Busleitung ist das Grüne Kabel.
Die b-Masseleitung ist Blau und mit den anderen blauen verbunden inkl. NodeMCU.

Das gelbe Kabel geht von GPIO23 über den 1K Widerstand zum roten Kabel und dann in den Transistor.

Wenn der ESP dran hängt sind auf der Bus Leitung noch 0,9V-2,1V, ansonsten 24V wenn die beiden GPIO nicht angeschlossen sind.

Dabei spielt es keine Rolle ob NodeMCU mit Strom versorgt wird oder nicht. In beiden Fällen bricht die Spannung direkt zusammen.

Siehst du da irgendeinen Fehler oder sollte das eigentlich so passen?

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

AzonInc, 2024-03-25:
Nachdem ich mal den Write Part rausgenommen habe und ausschließlich vom bus zu lesen versuche gibt es zwar keinen kurzschluss mehr aber daten bekomme ich auch keine.

AzonInc, 2024-03-25:
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
Mit dem D1 Mini bekomm ich auch keine Daten über den D5 Pin ausgelesen, egal ob man den Hörer hebt, die Tür öffnet oder klingelt.
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
AzonInc, 2024-04-06:
Ich nutze derzeit Fusion 360, das find ich eigentlich recht umgänglich dafür dass ich es das erste mal nutze.
Ich versuchs mal etwas breiter zu machen aber dennoch irgendwie die Platine im unteren Bereich zum klemmen zu machen.

AzonInc, 2024-04-07:
Habs nochmal neu gemacht, dieses mal etwas breiter.

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

AzonInc, 2024-04-07:
> > @calibanorg Wenn das sich umsetzen laesst, koennen wir auch gern mehrere Protokolle implementieren. Eventuell sollten wir die Issues aber aufsplitten. Also hier alles zum Thema PCB und passenden 3D Druck und fuer ein neues Protokoll bitte einfach ein neues Issue aufmachen.
>
> Np - ich mach ein neues issue auf fuer "Koch TC30 Integration"

Hab gerade mal geschaut und das Steuergerät ist selbst identisch mit TCS also wird das Protokoll wahrscheinlich identisch sein.
Bei Koch AG und TCS AG heißt das Teil (eins von mehreren) BVS20.

calibanorg, 2024-04-07:
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

wie von @peteh gewünscht habe ich ein neues issue eröffnet -> https://github.com/peteh/doorman/issues/19

alkue1, 2024-04-07:
Hey,
Hier geht's ja richtig vorwärts! :)
Deine Variante mit diode und Traco-Alternative wäre auch für mich mit der 3 Kabel installation interessant. Ich würde mich gerne auch bei der Bestellung mit anschließenden. Wie groß wäre denn der preisliche unterschied mit assembly des esp? Habe da ein bisschen Respekt bei meinem überschaubaren Löt skills :D

AzonInc, 2024-04-07:
@peteh Ich dachte bisher dass bei mir das Netzteil der TCS nicht reicht aber mir wurde letztens erklärt dass bei 24V Eingansspannung mit 60mA im Idealfall die Ausgangsleistung bei 1440mW liegt.
Dementsprechend stehen bei 1440mW / 3,3V = 436mA zur Verfügung. Das würde bedeuten dass der ESP locker auch von der P-Leitung bei einem BVS20 betrieben werden kann (ich habe sogar eine ungenutzte P-Leitung). In seltenen Fällen können Spannungsspitzen des ESPs allerdings für einen Neustart sorgen (Dafür wäre dann der optionale Kondensator).

AzonInc, 2024-04-07:
> Hey, Hier geht's ja richtig vorwärts! :) Deine Variante mit diode und Traco-Alternative wäre auch für mich mit der 3 Kabel installation interessant. Ich würde mich gerne auch bei der Bestellung mit anschließenden. Wie groß wäre denn der preisliche unterschied mit assembly des esp? Habe da ein bisschen Respekt bei meinem überschaubaren Löt skills :D

In Summe sind das glaub ich 30€ Aufpreis für alles gewesen.

alkue1, 2024-04-07:
> @peteh Ich dachte bisher dass bei mir das Netzteil der TCS nicht reicht aber mir wurde letztens erklärt dass bei 24V Eingansspannung mit 60mA im Idealfall die Ausgangsleistung bei 1440mW liegt. Dementsprechend stehen bei 1440mW / 3,3V = 436mA zur Verfügung. Das würde bedeuten dass der ESP locker auch von der P-Leitung bei einem BVS20 betrieben werden kann (ich habe sogar eine ungenutzte P-Leitung). In seltenen Fällen können Spannungsspitzen des ESPs allerdings für einen Neustart sorgen (Dafür wäre dann der optionale Kondensator).

:D genau das habe ich auch gerade gerechnet ... davon wird noch die Effizienz des spannungswandlers (bei deiner variante ca 80%) abgehen, müsste aber trotzdem dicke reichen. Mit einem traco +Kondensator habe ich es auch schon erfolgreich am kleinen Netzteil betrieben. Das einzige Problem waren Störgeräusche. Da habe ich jetzt voll Hoffnung in die Filter Schaltung....

Ich könnte mit 6 euro zusätzlich leben, würde zur Not aber auch den Lötkolben in die Hand nehmen ;)

AzonInc, 2024-04-07:
Den ESP hätte ich bereits hier liegen, dazu nen Heißlust Föhn und eine Wärmeplatte steht auch zur Verfügung.
Ich denke mal das sollte kein Problem sein den da draufzubekommen

peteh, 2024-04-07:
@AzonInc ich hab fuers 3D Case auch mal ein separates Issue angelegt, dann koennen wir hier die Details zum PCB weiter besprechen

#20

Wenn du deine STLs dort hoch laedst kann ich ein paar Testprints mit deinen Modifikationen machen und dir Feedback geben. Wenn die PCBs da sind und reinpassen schick ich dir logischerweise auch ein Case.

alkue1, 2024-04-07:
> Den ESP hätte ich bereits hier liegen, dazu nen Heißlust Föhn und eine Wärmeplatte steht auch zur Verfügung. Ich denke mal das sollte kein Problem sein den da draufzubekommen.
>

Cool, der Rest ist jetzt wohl ausprobieren :)
also ich wäre dir sehr verbunden, wenn du mir ein Exemplar (am besten mit ESP) natürlich gegen entsprechende Unkosten zukommen lassen könntest...

AzonInc, 2024-04-10:
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
Das wäre noch eine alternative Variante ohne platz für den optionalen
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

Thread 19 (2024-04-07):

Koch TC30 Integration

calibanorg, 2024-04-07:
### New Thread für die TC30 Integration von Koch

**Ziel:**
- Test ob Doorman mit TC30 funktioniert Out of the box

Folgendes wurde bereits geklärt in Issue [Board Design Frage](https://github.com/peteh/doorman/issues/17) mit @Azoninc

- TC30 KOCH ist die CH (Schweizer) version von TCS
- a (DC+) und b (DC-) sind auf 24v
- 6ms, 2ms, 4ms datenblöcke sind vorhanden
- Steuergerät ist vermutlich BVS20

**TC30 Anschluss Platte**

Anmerkung zum Bild: bei a + b sind ein schwarzes und weisses Kabel zusätzlich angehängt - diese sind separat und gehören nicht zur TC30 installation. Sie wurden für die Nello installation verwendet.

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

**Tür Öffnungs Trigger**

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

Hier noch die Schemas von TC:Bus plus Beiblatt
[Schema TC_Bus _ 1 Eingang, Anbindung an IP-Netzwerk, pot.freier Türöffnerkontakt - TC204_AVS 2100_LR12ACF.pdf](https://github.com/peteh/doorman/files/14896566/Schema.TC_Bus._.1.Eingang.Anbindung.an.IP-Netzwerk.pot.freier.Turoffnerkontakt.-.TC204_AVS.2100_LR12ACF.pdf)
[Beiblatt zu Schemas TCBus.pdf](https://github.com/peteh/doorman/files/14896567/Beiblatt.zu.Schemas.TCBus.pdf)
[Beiblatt zu Schemas TCBus.pdf](https://github.com/peteh/doorman/files/14896568/Beiblatt.zu.Schemas.TCBus.pdf)
[Schema TC_Bus _ 1 Eingang, Anbindung an IP-Netzwerk, pot.freier Türöffnerkontakt - TC204_AVS 2100_LR12ACF.pdf](https://github.com/peteh/doorman/files/14896569/Schema.TC_Bus._.1.Eingang.Anbindung.an.IP-Netzwerk.pot.freier.Turoffnerkontakt.-.TC204_AVS.2100_LR12ACF.pdf)

peteh, 2024-04-07:
Wenn das Protokoll identisch ist koenntest du den Aufbau einfach mal dran haengen und schauen ob er was liest.
Hier wuerde auch der Leseteil nur mit Spannungsteiler erst mal reichen.

calibanorg, 2024-04-07:
Ich baue mal dein Teil nach gemäss deiner Doku und hänge es dran. Das Material habe ich zusammen oder bei Amazon bestellt ausser die 2x 1.2 Ohm Widerstand, der ist tricky einzeln zu finden :-) werde dann meinen Tests hier rapportieren.

AzonInc, 2024-04-07:
Die 2x1,2 Ohm Widerstände benötigst du auch nicht. Funktioniert ohne die problemlos.

calibanorg, 2024-04-07:
was für einen Transitor hast Du verwendet? Ich hab noch einen 740DV LM35 DZ gefunden

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

AzonInc, 2024-04-07:
BC517 ist das BC817 ist im Board Design.

gee33, 2024-04-07:
Hallo zusammen,
Ich
Lese hier seit langem mit. Die Koch Anlage ist 100% zu TCS kompatibel, bzw. Ist eigentlich nur umgelabelt. Ich habe so einen ähnlichen setup bei mir seit 3 jahren am Laufen.  Ausser dem Türöffner, da habe ich der Einfachheit halber ein relais verwendet , dass einen Tastendruck simuliert.
Ich würde bei einer Platine aber mitmachen, dann könnte ich mein setup mal wieder modernisieren:-)
Komponenten würde ich selbst sourcen, btw. aus meinem Fundus nehmen.
Ich habe hinter der Steckdosenkombi unter der TC50 ein unterputz  usb netzteil eingebaut. Somit brauche ich den Spannungswandler 24-3.3v nicht.
Bin in der Schweiz.

AzonInc, 2024-04-07:
@gee33 derzeit hatte ich geplant 5 Stück zu bestellen die alle gleich sind.
Alles was planmäßig auf dem Board nicht drauf wäre sind Schraubklemme, Pin Header und ESP.
Alle anderen SMD Teile sind bereits bei Assembly dabei da die bei allen 5 gleich sein wird.

Ich habe hier noch die v1.0 Boards liegen, da sind gar keine Teile drauf da die nur zum Test waren. Wenn du gern 0402 SMD Komponenten da drauf machen möchtest kannst du da gern eins haben. Die haben allerdings auch keine RGB LED (Nur zwei normale Status LEDs vorgesehen) und kein Relais. vorgesehen. Nur die normale Schaltung für die Bus Kommunikation.
Dazu kommt noch dass die Traco Teile da noch eingeplant sind.

V1.0:
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

Müsste man mal schauen wie man das am besten macht. Je nachdem wie viele Leute das noch haben wollen.

peteh, 2024-04-07:
Mein Nachbar moechte seinen auch ersetzen. Also du kannst mich gern fuer 2 Boards einplanen.
SMD Loeten wuerde ich aber gern vermeiden. THT ist kein Problem.

- Kann man in dem Aufbau auch ueber USBC flashen oder braeuchte man einen Flasher?
- Kannst du beim TCS Bus eventuell noch A, B und P labeln?

AzonInc, 2024-04-07:
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

So siehts insgesamt aus wenns gelifert wird.

peteh, 2024-04-07:
Ah ok, unten sieht mans. Ich dachte nur dass es oben sinnvoller waer, weil wenn es im Case ist, sieht man die Labels nicht aber ich muss es im Case anschliessen.

AzonInc, 2024-04-07:
Stimmt an das Case hab ich anfangs nicht gedacht da ich das Teil so in das Telefongehäuse stecken werde.
Platztechnisch passt da nicht mehr wirklich was auf die Vorderseite. Bzw. ist das ja eh alles schon so klein.
Ich könnte da noch ein + hin packen wo P ist auf der vorderseite, dann weißt du bescheid.

peteh, 2024-04-07:
Das oder ein P vielleicht

calibanorg, 2024-04-08:
ich hab mal mit meinem Breadboard das ganze aufgebaut gemäss @peteh wiring. was ich spezifisch ausgelassen habe sind die Button/LED wiring und die 2 1.2 Ohm Widerstände (gemäss @AzonInc brauchts die nicht). Auf P habe ich "nur" 6v gemessen sprich den D1 habe ich moment via USB direkt laufen lassen. Leider bekomme ich kein signale auf dem TC:BUS.

ist mein wiring korrekt? evtl. habe ich keine gute Verbindungen wenn ja.

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

peteh, 2024-04-08:
Irgendwie fehlt ein Widerstand vom Spannungsteiler für d5 oder? Was misst du denn mit dem oszi am d5?

gee33, 2024-04-08:
@AzonInc ich würde dann auch eine mit smd bestückte Platine nehmen. Kannst mich also fix einplanen.

calibanorg, 2024-04-08:
> Irgendwie fehlt ein Widerstand vom Spannungsteiler für d5 oder? Was misst du denn mit dem oszi am d5?

Ja Widerstand hat gefehlt - hab das im Schema übersehen 🤦  - hab mir vermutlich grad mein wemos d1 gebraten 😞. Mit einem anderen Wemos bekomme ich die Signale wie vorgesehen. Leider habe ich gemerkt das mein ULN2003 ein APG ist nicht ein A - sprich der gibt nur 2.5 Volt aus, wenn ich das richtig gelesen habe. Muss noch warten bis ich die A version kriege das ich auch Befehle losschicken kann.

AzonInc, 2024-04-08:
Ich glaube ich hatte auch mal so einen ULN aber in meiner Erinnerung hat das trotzdem funktioniert.

calibanorg, 2024-04-08:
nope war nicht der Widerstand. GND hat gefehlt zum WEMOS. Als ich mich entschieden habe den Traco nicht nutzen, habe ich nicht daran gedacht GND wieder anzuschliessen. Jetzt funktionierts 🍾, ich kann alles machen :-). P habe ich nochmals gemessen beim direkten Ausgang und bekomme 22.8 Volt. Sprich meine wacklige Verkablung hat mir falsch Werte gegeben.

@peteh &  @AzonInc  danke für die Hilfe bei debuggen

Hier noch die funktionierende Breadboard variante:
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

calibanorg, 2024-04-08:
@peteh beim kompilieren hats mir noch einen Fehler angezeigt bei main.cpp zeile 567 -

`esp_restart()` ging nicht und ich habe es mit `system_restart();` ersetzt (wurde automatisch vorgeschlagen)

peteh, 2024-04-08:
Ah sorry, ich hab vermutlich wieder aus Versehen ESP32 spezifischen Code ohne #ifdef rein gebaut als ich den forcierten Neustart eingebaut habe, wenn keine WiFi Verbindung zustande kommt. Ich benutze fuer meinen hier einen S3 Mini. Der passt als Drop In und hat eine nette neopixel Led.

Beheb ich die Tage mal.

calibanorg, 2024-04-08:
Wie schon erwähnt funktioniert mein Testaufbau. Nun wenn ich P anschliesse gemäss Schema fällt die Spannung auf 6~V runter und der TSR12450 vOut bringt noch ca 1.2v. Könnte man nicht A direct auch an TSR anschliessen? evtl noch einen Capacitor dazwischen für die Spannung zu halten - überlegung aus meinem limitierten wissen.

AzonInc, 2024-04-08:
Was passiert denn wenn du ausschließlich den TSR anschließt ohne alles andere?

calibanorg, 2024-04-08:
Nur B (GND) und P (20V) = 5V via TSR alles andere nicht angehängt.

AzonInc, 2024-04-08:
Okay gut und was, wenn du mal den transistor weglässt bzw den teil allgemein zum senden von daten?

calibanorg, 2024-04-10:
Heute nochmals getestet. TSR mit GND und P zu Vin verbunden, GND mit WEMOS D1 GND und Vout mit Wemos D1 5v verbunden. Effekt sobald ich das mache fällt die Spannung auf ca 6.3V, der Strom ist bei ca 19mA zwischen 5v und Vout.

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

calibanorg, 2024-04-10:
ich hab mal einfach so den TSR mit a (V+) und b (GND) verbunden. Das klappt ja solange die Spannung stabil bleibt. Könnte man dann nicht einem Kondensator (470uF 16V) arbeiten um die 5V stabil zu halten? ich hab mal das diagram von @peteh  genommen und angepasst - mit meinem minimalen elektrotechnischen Kenntinissen.

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

calibanorg, 2024-04-12:
Meine dirty Lösung ist ein Battery Wemos Shield mit einer 1500mAH 3.7V Batterie. Nello (eine Müncher Firma die insolvenz gegangen ist) die haben auch nur a + b verwendet und dort hatten wir keine Störung mit Lautsprecher.

@peteh ich glaube das issue kann man schliessen. Ziel das es mit KOCH TC30 funktioniert ist erreicht.

AzonInc, 2024-04-12:
Eventuell liegt es ja dann tatsächlich an dem TSR. Bleibt abzuwarten bis ich es dann mal mit dem neuen Converter testen kann.

calibanorg, 2024-04-12:
Ich habe ein 24v Shield für WEMOS D1 (https://www.wemos.cc/en/latest/d1_mini_shield/dc_power.html) probiert. Der Effekt war der gleiche. Nello.io hat das irgendwie gelöst nur mit a + b zu verwenden ohne Störung. Leider finde ich das Gerät nicht mehr, habs vermutlich aus Wut entsorgt 🤦‍♂️, dann könnte man das PCB anschauen wie die das gelöst haben.

AzonInc, 2024-04-12:
Im Nello ist ein Superkondensator welcher das Problem wahrscheinlich gelöst hat.

calibanorg, 2024-04-12:
Weisst du wie gross der ist (uF)? Angehaengt vor TSR (24v) oder nach (5V)?

AzonInc, 2024-04-12:
Gute Frage, dazu hab ich nichts weiter gefunden aber das Ding ist im Endeffekt wie ein Akku und braucht ein paar sekunden bis der aufgeladen ist. Verhältnismäßig groß von der Bauform noch dazu.

peteh, 2024-04-15:
FYI, ein Freund von mir hat seinen alten Nello mal aufgemacht - ist aber wohl die erste HW Revision und es gab spaeter noch neuere:

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

peteh, 2024-05-26:
@calibanorg brauchen wir das issue noch? Die PCB Version vom doorman scheint gut zu laufen in den ersten Tests und Koch ist wohl identisch zu tcs. Dann würde ich hier zu machen

calibanorg, 2024-05-26:
@peteh ja wir können den issue schliessen

peteh, 2024-05-26:
Closed

Closed 2024-05-26.

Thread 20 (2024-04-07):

3D Case fuer PCB

peteh, 2024-04-07:
Um die Diskussion von 3d Gehause und PCB etwas zu isolieren hier das Issue fuers 3d Case.

AzonInc, 2024-04-07:
Stimmt, das ist etwas ausgeartet haha.
Hier die aktuellen Dateien Stand vor einer halben Stunde:
https://azon.ai/doorman-s3/enclosure/Cover.stl
https://azon.ai/doorman-s3/enclosure/Enclosure.stl

peteh, 2024-04-07:
Man koennte auch ueberlegen ob man ins Case ein paar Loecher fuer neodym magnete macht und dann dann eine zusaetzliche Plate mit Bohrloechern die auch Magnete hat. Dann koennte man die Box einfach "andocken"

peteh, 2024-04-07:
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

Now the holes for the leds are a bit too close again as it seems. At least the first test print didn't work out.

AzonInc, 2024-04-07:
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
Besser so?
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
Und spielt refinement eine Rolle?

peteh, 2024-04-07:
Hab das vorhergehende Modell noch mal mit meinem weissen Filament gedruckt, da hats geklappt. Scheint also auf dem kritischen Pfad zu sein. Ich drucke gerade das Case - erst mal ohne Support um zu sehen ob er das grosse Loch auch so schafft, ich vermute aber dazu muss man Support nutzen (automatisch generierte Stuetzen vom Slicer).

Ich lass den Druck gerade laufen und poste dann wieder die Ergebnisse. Irgendwie hab ich heute aber ein bisschen Probleme mit der Betthaftung.

peteh, 2024-04-07:
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

Das ist jetzt der Druck aus den Dateien die du initial hochgeladen hast (ohne den vergroesserten Platz zwischen den LEDs). Gedruckt auf einem Bambu P1S.

Musste den Drucker einmal kalibrieren lassen und die Druckplatte wieder ein bisschen klebriger machen. Jetzt lief der Druck gut durch. Sollte aber unabhaengig von den 3D-Dateien sein und normalerweise ganz gut durckbar sein.

Die Rastung sollte man vielleicht nicht ganz so stark machen, eventuell reicht halb so dick. Das Gehaeuse laesst sich nur extrem schwer wieder aufmachen.

AzonInc, 2024-04-07:
Okay dann werd ich die etwas schmaler machen. Was hälst du davon die LED Stab Führung ein Stück weiter nach unten zu ziehen?
Dann sitzte der Stab wirklich stabil in der Führung

peteh, 2024-04-07:
Gute Idee, du musst nur aufpassen, dass beim Anstellen des Klickverschlusses nichts rechts oder links haengen bleibt. Also wenn eine Seite einrastet und die andere noch nicht, dass man nicht an irgendwelchen Bauteilen vom Board haengen und ggf. was kaputt machen kann.

AzonInc, 2024-04-07:
In dem Fall wäre da jetzt nur der ESP und auf der anderen Seite nichts - ich machs vlt etwas dünner oder schräg

AzonInc, 2024-04-07:
Cover.stl hab ich überarbeitet, kannst die nochmal probieren ob die besser wieder geöffnet werden kann

AzonInc, 2024-04-07:
https://www.ebay.de/itm/275131695815
Das war das günstigste an LWL was ich finden konnte inkl. Versand.
Aber Acryl Stäbe funktionieren wahrscheinlich auch.

peteh, 2024-04-07:
> https://www.ebay.de/itm/275131695815 Das war das günstigste an LWL was ich finden konnte inkl. Versand. Aber Acryl Stäbe funktionieren wahrscheinlich auch.

Hab Mal 2mm und 3mm geordert und probiere Mal aus wie es mit einer beliebigen Led aussieht wenn es im Gehäuse ist.

peteh, 2024-04-07:
Was mir gerade noch aufgefallen ist, eventuell sollte man unten ins Gehäuse auch noch ein Loch machen, da kann das PCB sonst eventuell nie wieder raus bekommt ohne das Gehäuse zu zerstören

AzonInc, 2024-04-07:
Ich wollte eigentlich so ein Belüftungsgitter da hin machen aber habe noch nicht herausgefunden wie man das am besten anstellen kann.

peteh, 2024-04-07:
Normalerweise zeichnest du das Muster und nutzt dann eine "Loch"-Funktion, die das Material basierend auf dem Pattern von der Geometrie entfernt. Zumindest ist es so in Freecad

Vielleicht sowas (Fusion 360): https://www.youtube.com/watch?v=CxAtffOpu34

AzonInc, 2024-04-07:
Okay schaut gut aus. Sag mal wenn man LWL nutzt dann ist das ja gewissermaßen biegbar. Dementsprechend könnte man der Führung zu den LEDs auch eine leichte Kurve geben. damit es am Ende genau da ankommt wo es eigentlich hin sollte.

peteh, 2024-04-08:
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

Hier Mal Bilder vom letzten Druck.

Geht immer noch etwas schwer auf und mir ist aufgefallen, dass wenn man das ganze wieder auf macht reißen bzw biegen die oberen Layer an den Einrückungen nach oben. Eventuell sollte hab die etwas tiefer setzen

AzonInc, 2024-04-08:
Das schaut doch schon ganz solide aus.
Ich werde die Kerbe weiter nach unten versetzen und dann kann man später nochmal einen testdruck machen wenn das Board da ist.

Geht es denn genau so schwer auf wie vorher oder ist es etwas besser geworden?

peteh, 2024-04-08:
Gefuehlt etwas besser, aber mit dem Fingernagel bekommt man es nicht auf - mit einem Gemuesemesser klappts.

AzonInc, 2024-04-08:
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
Hab es jetzt nochmal ein stück weiter reingeschoben und weiter nach unten

peteh, 2024-04-08:
Schwierig zu sagen, du kannst zusaetzlich auch den ganzen Rahmen etwas einrücken vom Deckel. Dann schliesst er nicht auf den Millimeter mit der unteren Wand ab und laesst sich vlt etwas besser oeffnen.

AzonInc, 2024-04-08:
Und oben der Rand über der Kerbe ist jetzt 1,10mm stark, der sollte sich nicht mehr biegen

peteh, 2024-04-08:
Ich werds dann mal testen wenn die PCBs am Start sind um ein bisschen die Muellproduktion zu minimieren fuer den Moment.

Naechste Woche kann ich mal testen wie gut die LED "Weiterleitung" funktioniert wenn die Glasfasern da sind.

AzonInc, 2024-04-08:
Genau, wir finden schon noch raus ob was geändert werden muss.
Ich bin gespannt wie gut das Licht da durchgeht.

AzonInc, 2024-04-12:
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
Hast du ne Idee wie man dafür am besten das Case gestalten kann?
Da ist jetzt zusätzlich auch ein loch als Befestigung.

peteh, 2024-04-12:
Du kannst nach rechts ja beliebig Platz zu den loechern lassen, die muessen ja nicht genau buendig mit der Gehausewand sein.

Dann muesstest du es schraeg mit der USB Buchse nach unten einsetzen koennen.

Dann koenntest du kleine Rasten unten bei der USB Buchse und oben bei Status und RST machen um es ins Gehaeuse zu klipsen. Nach rechts laesst du dann eine groessere Aussparung oder machst den Deckel so, dass er das Dach bildet fuer die Schraubleiste. Dann muss man keinen Support beim Drucken verwenden und bekommt es vlt auch einfacher wieder auf.

AzonInc, 2024-04-12:
> Du kannst nach rechts ja beliebig Platz zu den loechern lassen, die muessen ja nicht genau buendig mit der Gehausewand sein.
>
> Dann muesstest du es schraeg mit der USB Buchse nach unten einsetzen koennen.

Wie meinst du das?

AzonInc, 2024-04-13:
Zum reindrücken weiß ich nicht ob das dann am ende so passt:
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

Je nach Drucktoleranz ist es zu wenig oder es passt

peteh, 2024-04-14:
Waere vielleicht besser da Nasen zu nehmen wie auch in deiner ersten Version beim Deckel. Quasi nur eine leichte Verdickung damit das Board etwas fixierter ist nach oben hin. Harte Ueberhaenge sollte man beim 3D Druck moeglichst vermeiden.

AzonInc, 2024-04-14:
War das jetzt auf das letzte bezogen oder das hier:
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

AzonInc, 2024-04-25:
@peteh gabs zwecks LWL schon was neues?

peteh, 2024-04-25:
Die liegen hier neben mir als 2mm und 3mm. Allerdings lieg ich mit grippalem Infekt auch nur rum. Ich denke naechste Woche kann ich es mal ausprobieren. Die Loecher muessen auf jeden Fall noch etwas groesser damit sie durch passen.

AzonInc, 2024-04-25:
Na dann erstmal gute Besserung :)
In 2-3 Wochen kann man dann endlich mal mehr testen

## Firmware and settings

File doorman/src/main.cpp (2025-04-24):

#include <Arduino.h>
#include <DNSServer.h>
#include <random>

#ifdef ESP8266
#include <ESP8266WiFi.h>
#include <ESP8266mDNS.h>
#endif

#ifdef ESP32
#include <WiFi.h>
#include <mdns.h>
// watch dog
#include <esp_task_wdt.h>
#endif

//#include <WiFiUdp.h>
#include <ArduinoOTA.h>
#include <LittleFS.h>
#include <esplog.h>

#include <ArduinoJson.h>
#include <PubSubClient.h>

#include <TCSBus.h>
#include <TriggerPatternRecognition.h>

#include <MqttDevice.h>

#include "apiserver.h"

#include "platform.h"
#include "utils.h"
#include "config.h"
#include "html.h"
#include "mqttview.h"

const uint WATCHDOG_TIMEOUT_S = 30;
const uint WIFI_DISCONNECT_FORCED_RESTART_S = 60;

WiFiClient net;
PubSubClient client(net);
MqttView g_mqttView(&client);

Settings g_settings;
ApiServer server(&g_settings);

#ifdef DOORMAN_S3
#define SUPPORT_RGB_LED 1
#define RGB_LED_PIN 2
#endif

#ifdef SUPPORT_RGB_LED
#include "led_rgb.h"
Led *g_led = new LedRGB(RGB_LED_PIN);
#else
#include "led_builtin.h"
Led *g_led = new LedBuiltin(LED_BUILTIN);
#endif

const char *HOMEASSISTANT_STATUS_TOPIC = "homeassistant/status";
const char *HOMEASSISTANT_STATUS_TOPIC_ALT = "ha/status";

const uint32_t CODE_DISCOVERY_REQUEST = 0x7FFF;
const uint8_t TCS_WRITER_SEND_WAIT_DURATION = 50;

TriggerPatternRecognition patternRecognitionEntry;
TriggerPatternRecognition patternRecognitionApartment;
TCSBusWriter tcsWriter(PIN_BUS_WRITE);
TCSBusReader tcsReader(PIN_BUS_READ);

uint32_t g_commandToSend = 0;
bool g_shouldSend = false;

bool g_ledState = false;
unsigned long g_tsLastLedStateOn = 0;

uint8_t g_handsetLiftup = 0;
unsigned long g_tsLastHandsetLiftup = 0;

bool g_wifiConnected = false;
bool g_mqttConnected = false;
unsigned long g_lastWifiConnect = 0;

String g_bssid = "";

bool connectToMqtt()
{
    if (client.connected())
    {
        return true;
    }

    log_info("Connecting to MQTT...");
    if (strlen(MQTT_USER) == 0)
    {
        if (!client.connect(composeClientID().c_str()))
        {
            return false;
        }
    }
    else
    {
        if (!client.connect(composeClientID().c_str(), MQTT_USER, MQTT_PASS))
        {
            return false;
        }
    }

    client.subscribe(g_mqttView.getApartmentBell().getCommandTopic(), 1);

    client.subscribe(g_mqttView.getEntryBell().getCommandTopic(), 1);
    client.subscribe(g_mqttView.getEntryOpener().getCommandTopic(), 1);

    client.subscribe(g_mqttView.getPartyMode().getCommandTopic(), 1);

    client.subscribe(g_mqttView.getBus().getCommandTopic(), 1);

    client.subscribe(g_mqttView.getConfigCodeApartmentDoorBell().getCommandTopic(), 1);
    client.subscribe(g_mqttView.getConfigCodeEntryDoorBell().getCommandTopic(), 1);
    client.subscribe(g_mqttView.getConfigCodeHandsetLiftup().getCommandTopic(), 1);
    client.subscribe(g_mqttView.getConfigCodeDoorOpener().getCommandTopic(), 1);
    client.subscribe(g_mqttView.getConfigCodeApartmentPatternDetect().getCommandTopic(), 1);
    client.subscribe(g_mqttView.getConfigCodeEntryPatternDetect().getCommandTopic(), 1);
    client.subscribe(g_mqttView.getConfigCodePartyMode().getCommandTopic(), 1);

    client.subscribe(g_mqttView.getDiagnosticsResetButton().getCommandTopic(), 1);

    client.subscribe(HOMEASSISTANT_STATUS_TOPIC);
    client.subscribe(HOMEASSISTANT_STATUS_TOPIC_ALT);

    // TODO: solve this somehow with auto discovery lib
    // client.publish(mqttTopic(MQTT_TOPIC_NONE, MQTT_ACTION_NONE).c_str(), "online");
    g_mqttView.publishConfig(g_settings);

    return true;
}

bool connectToWifi()
{
    return WiFi.status() == WL_CONNECTED;
}

void openDoor()
{
    delay(50);
    g_commandToSend = g_settings.getCodeSettings().codeDoorOpener;
    g_shouldSend = true;
}

void sendDiscoveryResponse()
{
    delay(50);

    uint8_t mac[6];
    WiFi.macAddress(mac);

    uint32_t response_command = 0x7F000000;
    response_command |= (mac[3] << 16) | (mac[4] << 8) | mac[5];

    g_commandToSend = response_command;
    g_shouldSend = true;
}

uint32_t parseValue(const char *data, unsigned int length)
{
    // TODO length check
    char temp[32];
    strncpy(temp, data, length);
    return (uint32_t)strtoul(temp, NULL, 16);
}

void callback(char *topic, byte *payload, unsigned int length)
{
    log_info("Message arrived [%s]", topic);
    for (unsigned int i = 0; i < length; i++)
    {
        Serial.print((char)payload[i]);
    }
    Serial.println();

    if (strcmp(topic, g_mqttView.getBus().getCommandTopic()) == 0)
    {
        uint32_t data = parseValue((char *)payload, length);
        g_commandToSend = data;
        g_shouldSend = true;
    }
    else if (strcmp(topic, g_mqttView.getEntryBell().getCommandTopic()) == 0)
    {
        g_commandToSend = g_settings.getCodeSettings().codeEntryDoorBell;
        g_shouldSend = true;
    }
    else if (strcmp(topic, g_mqttView.getApartmentBell().getCommandTopic()) == 0)
    {
        g_commandToSend = g_settings.getCodeSettings().codeApartmentDoorBell;
        g_shouldSend = true;
    }
    else if (strcmp(topic, g_mqttView.getEntryOpener().getCommandTopic()) == 0)
    {
        g_commandToSend = g_settings.getCodeSettings().codeDoorOpener;
        g_shouldSend = true;
    }

    else if (strcmp(topic, g_mqttView.getPartyMode().getCommandTopic()) == 0)
    {
        Settings::GeneralSettings generalSettings = g_settings.getGeneralSettings();
        generalSettings.partyMode = strncmp((char *)payload, g_mqttView.getPartyMode().getOnState(), length) == 0;
        g_settings.setGeneralSettings(generalSettings);
        g_settings.save();

        g_led->setBackgroundLight(generalSettings.partyMode);
        g_led->blinkAsync(); // force update of led
        g_mqttView.publishPartyMode(generalSettings.partyMode);
    }

    // Save config entries from Homeassistant
    else if (strcmp(topic, g_mqttView.getConfigCodeApartmentDoorBell().getCommandTopic()) == 0)
    {
        Settings::CodeSettings codeSettings = g_settings.getCodeSettings();
        codeSettings.codeApartmentDoorBell = parseValue((char *)payload, length);
        g_settings.setCodeSettings(codeSettings);
        g_settings.save();
        g_mqttView.publishConfigValues(g_settings);
    }
    else if (strcmp(topic, g_mqttView.getConfigCodeEntryDoorBell().getCommandTopic()) == 0)
    {
        Settings::CodeSettings codeSettings = g_settings.getCodeSettings();
        codeSettings.codeEntryDoorBell = parseValue((char *)payload, length);
        g_settings.setCodeSettings(codeSettings);
        g_settings.save();
        g_mqttView.publishConfigValues(g_settings);
    }
    else if (strcmp(topic, g_mqttView.getConfigCodeHandsetLiftup().getCommandTopic()) == 0)
    {
        Settings::CodeSettings codeSettings = g_settings.getCodeSettings();
        codeSettings.codeHandsetLiftup = parseValue((char *)payload, length);
        g_settings.setCodeSettings(codeSettings);
        g_settings.save();
        g_mqttView.publishConfigValues(g_settings);
    }
    else if (strcmp(topic, g_mqttView.getConfigCodeDoorOpener().getCommandTopic()) == 0)
    {
        Settings::CodeSettings codeSettings = g_settings.getCodeSettings();
        codeSettings.codeDoorOpener = parseValue((char *)payload, length);
        g_settings.setCodeSettings(codeSettings);
        g_settings.save();
        g_mqttView.publishConfigValues(g_settings);
    }
    else if (strcmp(topic, g_mqttView.getConfigCodeApartmentPatternDetect().getCommandTopic()) == 0)
    {
        Settings::CodeSettings codeSettings = g_settings.getCodeSettings();
        codeSettings.codeApartmentPatternDetect = parseValue((char *)payload, length);
        g_settings.setCodeSettings(codeSettings);
        g_settings.save();
        g_mqttView.publishConfigValues(g_settings);
    }
    else if (strcmp(topic, g_mqttView.getConfigCodeEntryPatternDetect().getCommandTopic()) == 0)
    {
        Settings::CodeSettings codeSettings = g_settings.getCodeSettings();
        codeSettings.codeEntryPatternDetect = parseValue((char *)payload, length);
        g_settings.setCodeSettings(codeSettings);
        g_settings.save();
        g_mqttView.publishConfigValues(g_settings);
    }
    else if (strcmp(topic, g_mqttView.getConfigCodePartyMode().getCommandTopic()) == 0)
    {
        Settings::CodeSettings codeSettings = g_settings.getCodeSettings();
        codeSettings.codePartyMode = parseValue((char *)payload, length);
        g_settings.setCodeSettings(codeSettings);
        g_settings.save();
        g_mqttView.publishConfigValues(g_settings);
    }

    else if (strcmp(topic, g_mqttView.getDiagnosticsResetButton().getCommandTopic()) == 0)
    {
        bool pressed = strncmp((char *)payload, g_mqttView.getDiagnosticsResetButton().getPressState(), length) == 0;
        Settings::GeneralSettings generalSettings = g_settings.getGeneralSettings();
        generalSettings.restartCounter = 0;
        generalSettings.mqttDisconnectCounter = 0;
        generalSettings.wifiDisconnectCounter = 0;
        g_settings.setGeneralSettings(generalSettings);
        g_settings.save();
        g_mqttView.publishDiagnostics(g_settings, g_bssid.c_str());
    }

    // publish config when homeassistant comes online and needs the configuration again
    else if (strcmp(topic, HOMEASSISTANT_STATUS_TOPIC) == 0 ||
             strcmp(topic, HOMEASSISTANT_STATUS_TOPIC_ALT) == 0)
    {
        if (strncmp((char *)payload, "online", length) == 0)
        {
            g_mqttView.publishConfig(g_settings);
        }
    }
}

void setup()
{
#ifdef ESP32
    // initialize watchdog
    esp_task_wdt_init(WATCHDOG_TIMEOUT_S, true); // enable panic so ESP32 restarts
    esp_task_wdt_add(NULL);                      // add current thread to WDT watch
#endif
    Serial.begin(115200);

    g_led->begin();
    // turn on led until boot sequence finished
    g_led->blinkAsync();

    delay(400);
    log_info("Starting to mount LittleFS");
    if (!LittleFS.begin())
    {
        log_error("Failed to mount file system");
        delay(5000);
        if (!formatLittleFS())
        {
            log_error("Failed to format file system - hardware issues!");
            for (;;)
            {
                delay(100);
            }
        }
    }
    log_info("Finished Mounting");

    g_settings.begin();
    Settings::GeneralSettings generalSettings = g_settings.getGeneralSettings();
    generalSettings.restartCounter++;
    g_settings.setGeneralSettings(generalSettings);
    g_settings.save();

    tcsWriter.begin();
    tcsReader.begin();

    // configure pattern detection
    patternRecognitionEntry.addStep(1000);
    patternRecognitionEntry.addStep(1000);

    // configure pattern detection
    patternRecognitionApartment.addStep(1000);
    patternRecognitionApartment.addStep(1000);

    WiFi.setHostname(composeClientID().c_str());
    WiFi.mode(WIFI_STA);
#ifdef ESP32
    // select the AP with the strongest signal
    WiFi.setScanMethod(WIFI_ALL_CHANNEL_SCAN);
    WiFi.setSortMethod(WIFI_CONNECT_AP_BY_SIGNAL);
#endif

    // TODO: boot in ap mode if apnextboot is set
    //WiFi.begin(g_settings.getWiFiSettings().staSsid, g_settings.getWiFiSettings().staPassword);
    WiFi.begin(DEFAULT_STA_WIFI_SSID, DEFAULT_STA_WIFI_PASS);

    log_info("Connecting to wifi...");
    // TODO: really forever? What if we want to go back to autoconnect?
    long startTime = millis();
    while (!connectToWifi())
    {
        if (millis() - startTime > WIFI_CONNECTION_FAIL_TIMEOUT_S*1000)
        {
            // we failed to connect to the wifi, force reboot in AP settings
            Settings::GeneralSettings settings = g_settings.getGeneralSettings();
            settings.forceAPnextBoot = true;
            g_settings.setGeneralSettings(settings);
            g_settings.save();
            ESP.restart();
        }
        log_debug(".");
        delay(500);
    }
    g_wifiConnected = true;
    g_lastWifiConnect = millis();

    log_info("Wifi connected!");

    log_info("Connected to SSID: %s", g_settings.getWiFiSettings().staSsid);
    log_info("IP address: %s", WiFi.localIP().toString().c_str());
    g_bssid = WiFi.BSSIDstr();

    char configUrl[256];
    snprintf(configUrl, sizeof(configUrl), "http://%s/", WiFi.localIP().toString().c_str());
    g_mqttView.getDevice().setConfigurationUrl(configUrl);

    client.setBufferSize(1024);
    client.setServer(MQTT_SERVER, MQTT_PORT);
    client.setCallback(callback);
    server.begin(); // Start the server
    log_info("Server listening");

    ArduinoOTA.onStart([]()
                       {
    String type;
    if (ArduinoOTA.getCommand() == U_FLASH) {
      type = "sketch";
    } else { // U_FS
      type = "filesystem";
    }

    // NOTE: if updating FS this would be the place to unmount FS using FS.end()
    log_info("Start updating %s", type.c_str()); });
    ArduinoOTA.onEnd([]()
                     { log_info("End"); });
    ArduinoOTA.onProgress([](unsigned int progress, unsigned int total)
                          {
// reset watchdog during update
#ifdef ESP32
            esp_task_wdt_reset();
#endif
        log_info("Progress: %u%%\r", (progress / (total / 100))); });
    ArduinoOTA.onError([](ota_error_t error)
                       {
    log_error("Error[%u]: ", error);
    if (error == OTA_AUTH_ERROR) {
      log_error("Auth Failed");
    } else if (error == OTA_BEGIN_ERROR) {
      log_error("Begin Failed");
    } else if (error == OTA_CONNECT_ERROR) {
      log_error("Connect Failed");
    } else if (error == OTA_RECEIVE_ERROR) {
      log_error("Receive Failed");
    } else if (error == OTA_END_ERROR) {
      log_error("End Failed");
    } });
    ArduinoOTA.begin();
}

void loop()
{
#ifdef ESP32
    // reset watchdog, important to be called once each loop.
    esp_task_wdt_reset();
#endif

    g_led->update();
    bool wifiConnected = connectToWifi();
    if (!wifiConnected)
    {
        if (g_wifiConnected)
        {
            // we switched to disconnected
            Settings::GeneralSettings generalSettings = g_settings.getGeneralSettings();
            generalSettings.wifiDisconnectCounter++;
            g_settings.setGeneralSettings(generalSettings);
            g_settings.save();
        }
        if (millis() - g_lastWifiConnect > WIFI_DISCONNECT_FORCED_RESTART_S * 1000)
        {
            log_warn("Wifi could not connect in time, will force a restart");
            ESP.restart();
        }
        g_wifiConnected = false;
        g_mqttConnected = false;
        delay(1000);
        return;
    }
    g_wifiConnected = true;
    g_lastWifiConnect = millis();

    server.handleClient(); // Handling of incoming web requests
    ArduinoOTA.handle();

    bool mqttConnected = connectToMqtt();
    if (!mqttConnected)
    {
        if (g_mqttConnected)
        {
            // we switched to disconnected
            Settings::GeneralSettings generalSettings = g_settings.getGeneralSettings();
            generalSettings.mqttDisconnectCounter++;
            g_settings.setGeneralSettings(generalSettings);
            g_settings.save();
        }
        g_mqttConnected = false;
        delay(1000);
        return;
    }
    if (!g_mqttConnected)
    {
        // now we are successfully reconnected and publish our counters
        g_bssid = WiFi.BSSIDstr();
        g_mqttView.publishDiagnostics(g_settings, g_bssid.c_str());
    }
    g_mqttConnected = true;

    client.loop();
    if (g_shouldSend)
    {
        uint32_t msNow = millis();
        std::srand(msNow);

        delay(std::rand() % 101 + 50); // 50-150
        while((msNow - tcsReader.lastBitTimestamp()) < TCS_WRITER_SEND_WAIT_DURATION)
        {
            delay(std::rand() % 101 + 50); // 50-150
        }

        uint32_t cmd = g_commandToSend;
        g_shouldSend = false;
        log_info("Sending: %08x", cmd);
        tcsReader.disable();
        tcsWriter.write(cmd);
        tcsReader.enable();
        // dirty hack to also publish commands we have written
        tcsReader.inject(cmd);
        g_led->blinkAsync();
    }
    if (tcsReader.hasCommand())
    {
        g_led->blinkAsync();
        uint32_t cmd = tcsReader.read();

        // Custom protocol: Doorman discovery request
        if (cmd == CODE_DISCOVERY_REQUEST)
        {
            sendDiscoveryResponse();
        }

        if (cmd == g_settings.getCodeSettings().codeApartmentDoorBell)
        {
            g_mqttView.publishApartmentBellTrigger();
        }

        if (cmd == g_settings.getCodeSettings().codeEntryDoorBell)
        {
            g_mqttView.publishEntryBellTrigger();
        }

        if (cmd == g_settings.getCodeSettings().codeDoorOpener)
        {
            g_mqttView.publishEntryOpenerTrigger();
        }

        if (g_settings.getGeneralSettings().partyMode && cmd == g_settings.getCodeSettings().codePartyMode)
        {
            // we have a party, let everybody in
            openDoor();
        }

        if (cmd == g_settings.getCodeSettings().codeHandsetLiftup)
        {
            if (millis() - g_tsLastHandsetLiftup < 2000)
            {
                g_handsetLiftup++;
            }
            else
            {
                g_handsetLiftup = 1;
            }
            g_tsLastHandsetLiftup = millis();

            if (g_handsetLiftup == 3)
            {
                Settings::GeneralSettings generalSettings = g_settings.getGeneralSettings();
                generalSettings.partyMode = !generalSettings.partyMode;
                g_settings.setGeneralSettings(generalSettings);
                g_settings.save();
                g_handsetLiftup = 0;
                g_led->setBackgroundLight(generalSettings.partyMode);
                g_led->blinkAsync();
                g_mqttView.publishPartyMode(generalSettings.partyMode);
            }
        }

        if (cmd == g_settings.getCodeSettings().codeEntryPatternDetect)
        {
            if (patternRecognitionEntry.trigger())
            {
                // TODO: make pattern configurable and enableable
                openDoor();
                g_mqttView.publishEntryBellPatternTrigger();
            }
        }

        if (cmd == g_settings.getCodeSettings().codeApartmentPatternDetect)
        {
            if (patternRecognitionApartment.trigger())
            {
                g_mqttView.publishApartmentBellPatternTrigger();
            }
        }

        log_info("TCS Bus: %08x", cmd);
        g_mqttView.publishBus(cmd);
    }
}

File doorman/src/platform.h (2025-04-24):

#pragma once
#include <Arduino.h>

#define VERSION "2025.04.0"

#ifdef ESP8266
#define PIN_BUS_READ D5
#define PIN_BUS_WRITE D6
#define SYSTEM_NAME "ESP8266 Doorman"
#endif

#ifdef ARDUINO_LOLIN_S3_MINI
#define SUPPORT_RGB_LED 1
#define RGB_LED_PIN 47
#endif

#ifdef DOORMAN_S3
#define PIN_BUS_READ 9
#define PIN_BUS_WRITE 8
#define SYSTEM_NAME "Doorman-S3"
#else
    #ifdef ESP32
    #define PIN_BUS_READ 12
    #define PIN_BUS_WRITE 13
    #define SYSTEM_NAME "ESP32 Doorman"
    #endif
#endif

const char DEFAULT_AP_PASSWORD[] = "doormanadmin";
const long WIFI_CONNECTION_FAIL_TIMEOUT_S = 60;

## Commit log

2022-02-16 CHG: refacotr, use correct mqtt id, dont listen while sending
    [main.cpp, ring.cpp]
2022-02-19 ADD: blink led when tests are finished.
2022-02-19 ADD: first draft of fritzing wiring
    [wiring.fzz]
2022-02-23 CHG: Update readme with wiring
    [wiring.fzz]
2022-03-01 ADD: mqtt topics, disable interrupt while writing to bus
2022-04-24 CHG: mqtt device registration
2022-04-24 FIX: mqtt device
2022-04-24 CHG: refactor mqttdevice and add device information
2022-04-25 CHG: update mqtt device lib
2023-01-19 FIX: sample config
2023-02-13 DEL: unused params from sample config
2023-02-22 ADD: initial support for esp32 s2mini
2023-05-07 FIX: buffer for mqtt was too small for full configuration
    [main.cpp]
2023-06-03 add error handling for publishing messages
    [main.cpp]
2023-07-24 Fix restart when saving config
    [main.cpp]
2023-07-24 Add rgb led support for s3 mini board
2024-01-16 FIX: don't use esp32 watchdog on esp8266
    [main.cpp]
2024-01-24 CHG: use siren instead of switch for bells, extract platform data
2024-01-27 FIX: call watchdog during ota update
    [main.cpp]
2024-01-28 FIX: d1 mini build
    [main.cpp, platform.h]
2024-04-08 FIX: compilation for ESP8266
    [main.cpp]
2024-10-22 ADD: force ap mode if connection to wifi fails
    [main.cpp, platform.h]
